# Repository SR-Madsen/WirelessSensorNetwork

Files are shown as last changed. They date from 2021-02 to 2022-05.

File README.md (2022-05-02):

# Wireless Sensor Network
STM32-based project for testing Internet of Things, Ethernet, RFID, and similar technologies.

## Repository Structure
This repository contains a folder for documentation, which includes datasheets and reference manuals used during the design phase as well as other tools and general documents. Additionally, there are folders for the Master board and Slave board. These further includes demo programs used for testing functionality that is possible to test on either the STM32F769-DISCO, STM32L412 Nucleo, or STM32WB55 Nucleo boards. The actual program used for each board is placed in a separate, aptly named, folder. The PCBs themselves are also found as KiCad projects within either the Master or Slave folder.

## Overview
The project will contain one large Master board with many functionalities and several small Slaves only used for measuring sensor values. The slaves are powered by a coin-cell battery, and will thus be in sleep mode most of the time. Occasionally, they will wake and retrieve sensor measurements, which are transmitted over 2.4 GHz ZigBee to the Master. The Master is supplied through USB and will, aside from receiving data from the Slaves, contain an RFID antenna used for detecting valid cards/keys, which allow the user to initiate a data transfer. This data transfer may be through USB or Ethernet, as the Master will host a small webpage containing the data from each Slave.

A full block diagram of the project can be found as draw.io files in the Documentation folder, but is also shown below. In the documentation folder, a LaTeX report can also be found.

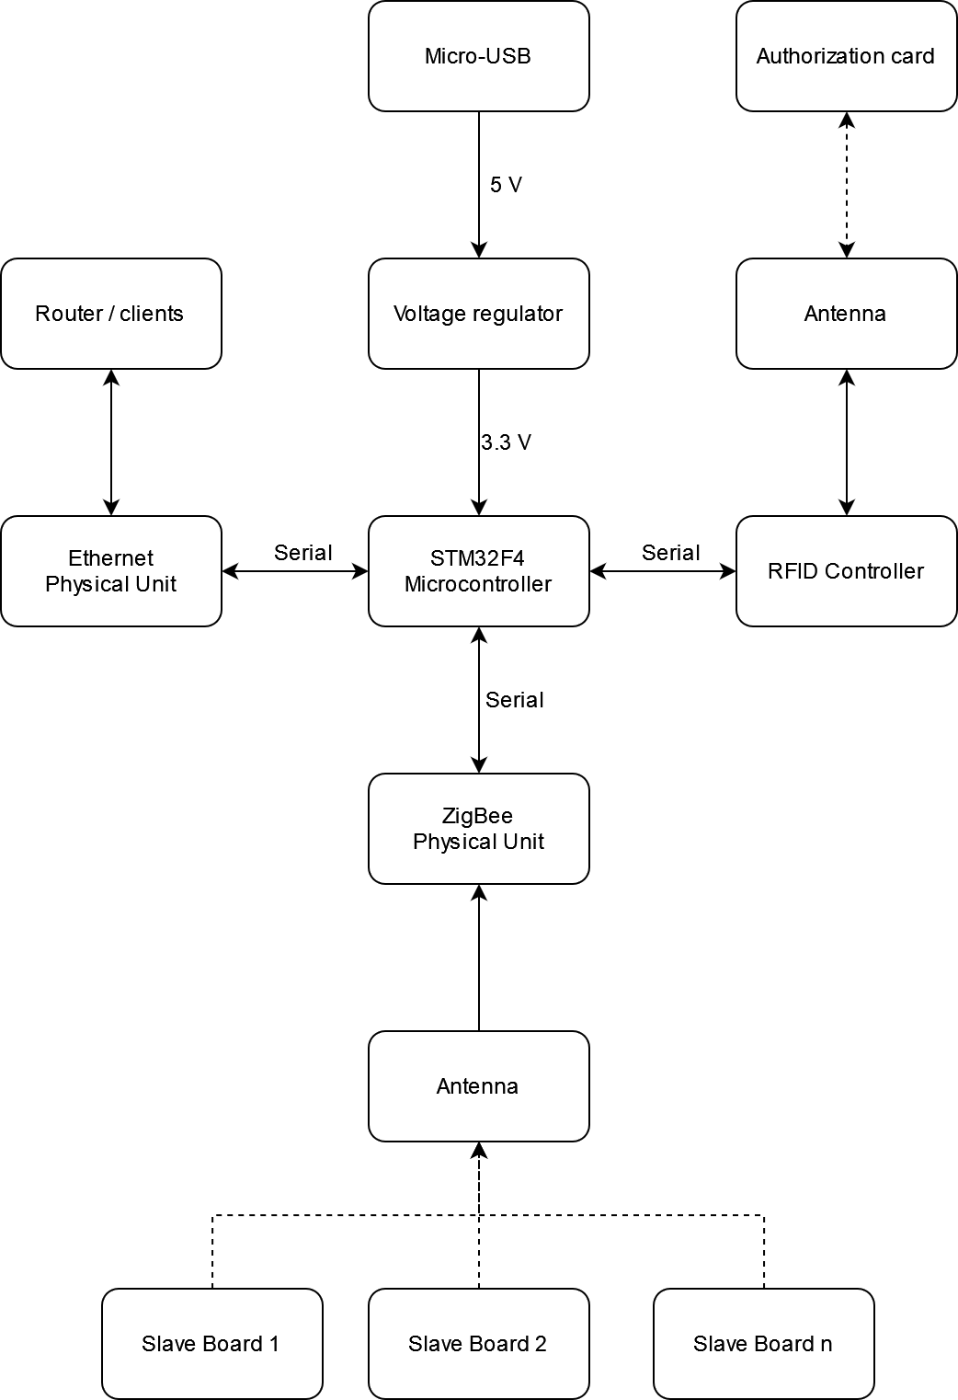
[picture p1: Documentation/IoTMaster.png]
Master board


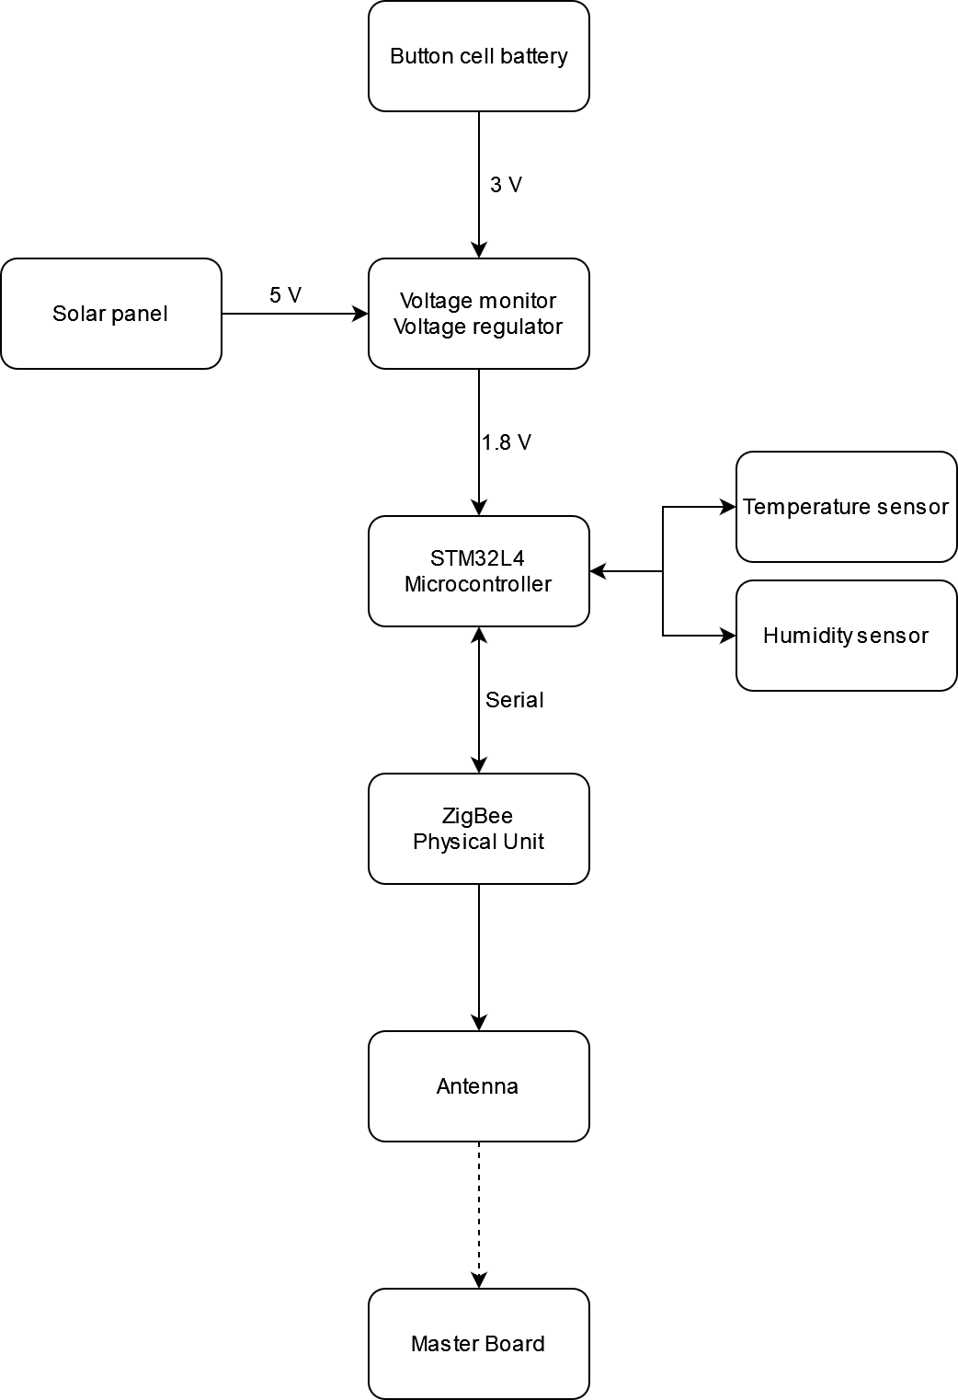
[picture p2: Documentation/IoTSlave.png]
Slave board


## Hardware
The designed PCBs are shown below.

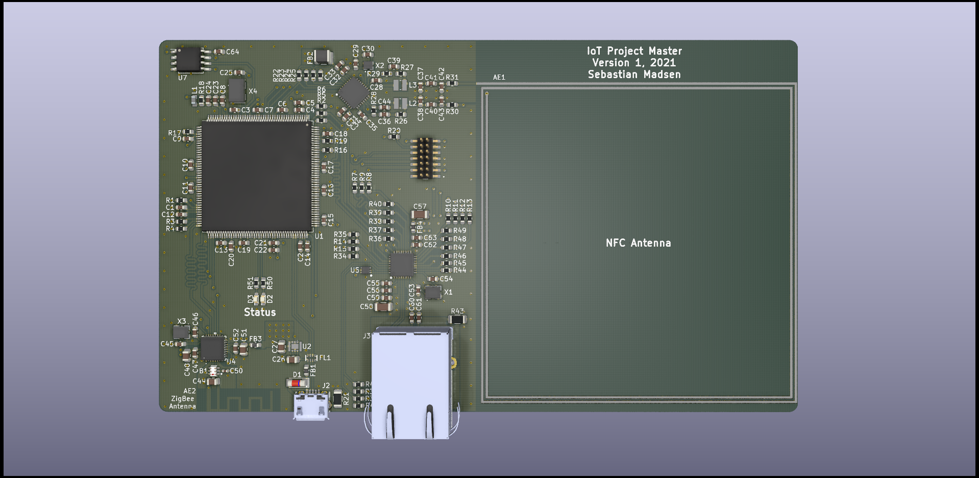
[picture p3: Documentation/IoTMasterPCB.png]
Master PCB


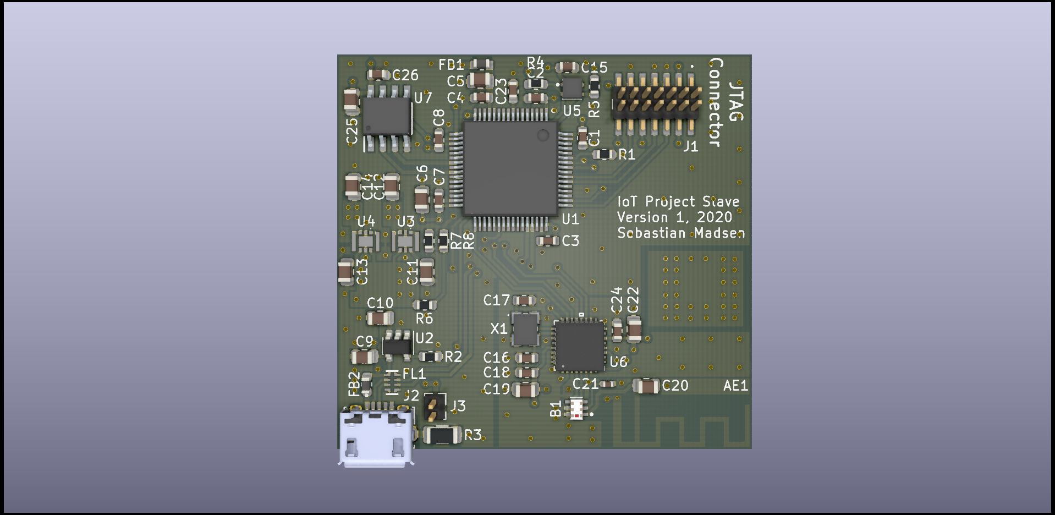
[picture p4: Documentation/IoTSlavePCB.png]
Slave PCB


## Software
By using ST development kits and the STM32Cube ecosystem, preliminary software has been created for both the master and slave.

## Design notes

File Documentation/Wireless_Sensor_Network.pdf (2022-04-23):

# Documentation of

# Wireless Sensor Network

### Sebastian Rud Madsen

### July 2020

1

Sebastian Rud Madsen | Wireless Sensor Network | July 2020

## Contents

1 About | 3
2 Idea | 3
3 Electrical Considerations | 4
4 Mechanical Requirements | 8
5 Hardware Choices | 9
University of Southern Denmark | Page 2 of 13

## 1 About

This documentation is used for thoughts, theory, and calculations in regards to

creating the IoT-like device. The project is to be used as a learning board for low-

power digital uses and IoT technologies, as well as general programming. The design

should mirror realistic engineering principles, with some components being designed

fully, while relevant components are simply bought as integrated circuits.

## 2 Idea

The project will result in slave boards that utilize an STM32L microcontroller in

low-power and shutdown-mode to conserve battery life. The battery should be a

button cell type, like the CR2032 or a rechargeable variant. The microcontroller will

get measurements of temperature and humidity and communicate these through a

wireless IoT communication type to a master controller, which is responsible for

multiple nodes. This will log the data for separate locations and continuously save

these, for example to a web-based solution for graphical output. To incorporate

RFID communication, the master controller could implement one as well, which

would transfer data to USB or similar action when a correct key is detected.

University of Southern Denmark | Page 3 of 13

## 3 Electrical Considerations

This section outlines the considerations and requirements for the electrical parts of

the system.

### 3.1 Analog Circuits

The analog circuits must accommodate the use of a battery. As a small 4-5 V solar

panel is accessible, which can be used to supply current for the circuit. For design

flexibility, both a non-rechargeable and a rechargeable variant of the same battery

will be usable. The rechargeable variant will be powered by the solar panel, which

also supplies the circuits themselves. The battery will supply the current when the

sun is not present. For this reason, a voltage regulator must be used to correct the

voltage for use in the battery. As a common cell battery is 3 V, a similar voltage is

expected for the rechargeable variant. To avoid undervoltage and overvoltage of the

battery, a window comparator or voltage monitor must be used as well as a charging

circuit. To reduce power consumption further, a low-voltage supply should be used.

As a voltage regulator is needed for the solar panel’s voltage output anyways, this

can easily be implemented.

The master controller will not be battery-driven, but instead powered through for

example micro-USB, as it will be placed in a stable environment with easy access to

power sources. It will still need use of a voltage regulator, but is much more flexible.

### 3.2 Digital Circuits

As mentioned, a low-power variant of the STM32 microcontroller will be used to re-

duce strain on the battery. This will be used in shutdown-mode most of the time, and

occasionally in low-power mode for gathering measurements and sending messages.

In shutdown-mode, it is expected to use no more than 250 nA, while it will draw at

most 1 mA when active. Additionally, a transceiver must also be used for the chosen

IoT technology. Once more, this will not use more than 500 nA in shutdown-mode,

but up to 15 mA when transmitting. This will be only for a short amount of time,

with large intervals.

University of Southern Denmark | Page 4 of 13

By estimating use of a 50 mAh battery with a 750 nA stop-mode 99.9% of the

time, only drawing 15 mA 0.1% of the time, the battery will last 132 days without

charging. This means that the microcontroller can transmit for 0.3 seconds every

5 minutes. This seems reasonable for real-life use, as temperatures and humidity

changes very slowly. A more expensive battery will contain a charge of up to 250

mAh, greatly prolonging the lifetime of the slave boards.

The master controller will not be using a battery, and thus its RFID and IoT

transceivers can realistically use any amount of power. The microcontroller used

in the master controller can be any STM-type, so long as it is powerful enough to

collect and distribute data both via antennas and ethernet. Additionally, a flash

storage connected to the microcontroller with QSPI would also be great for storing

the collected data.

### 3.3 RF Technology

As mentioned, RFID will be used for the master controller. This requires an antenna

of a sort, which can simply be routing on the PCB, for example by purchasing an

RFID-RC522 PCB and connecting it to the master controller board. Alternatively,

another option is designing an antenna manually, which requires precision, but is

cheaper and requires less space. As the project should mirror actual in-company

engineering, the latter option is the best.

For communication between master and slave boards, the 2.4 GHz ZigBee protocol

will be used, which is a well-defined IEEE 802.15.4-based specification. The range is

relatively short, but due to the limited distances within the apartment to be used,

this should not matter. There are many alternatives in IoT communication, some of

the biggest being Z-Wave, LoRa, and SigFox. ZigBee has been chosen solely because

it has a cooler logo, as the downsides as opposed to other technologies will not

impact this project.

University of Southern Denmark | Page 5 of 13

### 3.4 Summary

The considerations made through this section is summarized by creating block dia-

grams for both the Master and Slave boards. The Master board block diagram can

be seen in Figure 1, while the Slave block diagram can be seen in Figure 2.

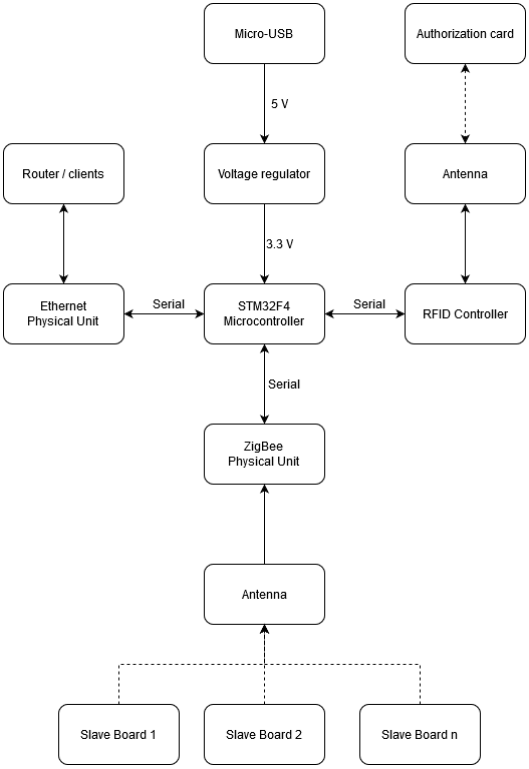
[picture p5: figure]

Figure 1: Block diagram of IoT Project Master Board

University of Southern Denmark | Page 6 of 13

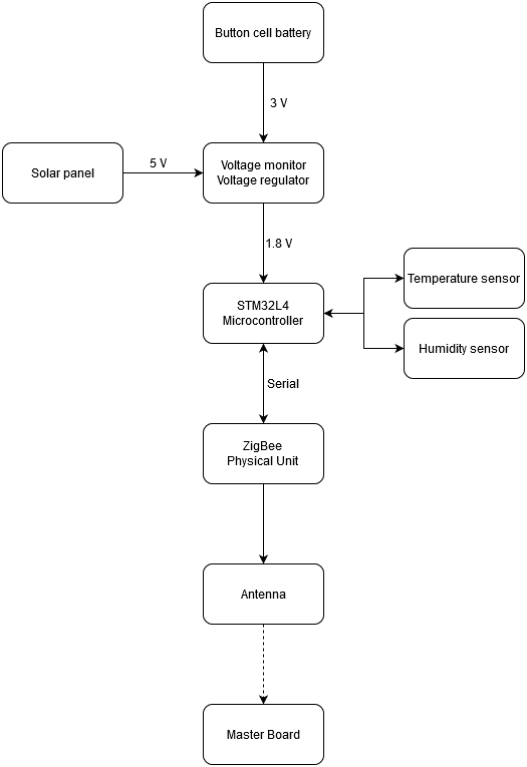
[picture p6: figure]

Figure 2: Block diagram of IoT Project Slave Boards

University of Southern Denmark | Page 7 of 13

## 4 Mechanical Requirements

This section similarly outlines the requirements for the mechanical parts of the

system.

University of Southern Denmark | Page 8 of 13

## 5 Hardware Choices

Using the electrical considerations, hardware can be chosen and electric circuits

designed for both the slaves and master.

### 5.1 Slave Boards

The Slave Boards are designed initially, as they have the most limitations. The

design choices made are clarified in the coming sections.

Microcontroller

A development board with the low-power microcontroller STM32L412RBT6P (https://www.mouser.dk/ProductDetail/STMicroelectronics/STM32L412RBT6P?qs=l7cgNqFNU1hh%252BU1wOZs5Xg%3D%3D) is

available, for which reason the MCU is chosen for the slave board. The additional

benefit of using an L4 microcontroller is the higher performance at lower power,

at a higher cost. The P-suffix indicates that the microcontroller can be used with

an external SMPS, as opposed to internal LDO, for increased power efficiency in

run-mode. This function may be left unused if it is deemed to be too pricey. Flash

memory accessed by QSPI should be placed on the board for future-proofing.

IoT Transceiver

The transceiver chosen for ZigBee is the AT86RF232-ZX from Microchip, (https://www.digikey.com/en/products/detail/microchip-technology/AT86RF232-ZXR/3046266) which is

cheap and allows use of an external antenna, which exists within KiCad. Commu-

nication with the microcontroller is through SPI, and also allows for GPIO pins to

indicate interrupts and reset. The transceiver is clocked by the ECS-160-16-33B-

CKM-TR 16 MHz crystal oscillator. (https://www.mouser.dk/ProductDetail/ECS/ECS-160-16-33B-CKM-TR)

Battery

The battery chosen for the slave board is the LIR2450 with a capacity of 120 mAh

and nominal voltage of 3.6 V. (https://dk.farnell.com/multicomp/lir2450/coin-cell-lithium-120mah-3-6v/dp/2009025) This battery can be recharged with 4.2 V. If the

rechargeable battery is deemed unneeded, a CR2450 can be used instead. This would

have a nominal voltage of 3 V, but a capacity of up to 500 mAh.

University of Southern Denmark | Page 9 of 13

The battery will be placed in the SMTU2450-LF from Renata, (https://www.mouser.dk/ProductDetail/Renata/SMTU2450N-LF-BULK?qs=LsPilcdHE7Gn4SDnejz9jQ%3D%3D) a holder designed for

batteries of size 2450.

The output voltage is regulated to 1.8 V with the MYRGP180100B21RA from Mu-

rata, (https://www.mouser.dk/ProductDetail/Murata-Electronics/MYRGP180100B21RA?qs=xZ%2FP%252Ba9zWqaqKk0PL2xouw%3D%3D) as it has high efficiency and small size. The 1.8 V are supplied instead of battery

voltage as it reduces power consumption of the microcontroller and used ICs. A 1.0

V variant of the MYRGP is used for supplying the core voltage and disabling the

internal LDO of the microcontroller, if found to be efficient.

Due to current consumption, the battery voltage cannot be measured by the mi-

crocontroller. If this is found to be needed, the DC-converter RP605Z183B-E2-F

from Ricoh Electronics (https://www.mouser.dk/ProductDetail/Ricoh-Electronic-Devices-Company/RP605Z183B-E2-F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) has high efficiency for supplying 1.8 V, and also divides the

battery voltage with low current consumption so that it can be measured by the

microcontroller. For the time being, a high-resistance voltage divider is implemented

to measure the voltage. The target current consumption is around 1 µA, which dou-

bles the idle consumption. If this impacts battery life too much, the resistors should

be desoldered.

A connection is made for a solar panel to supply the MCP73831T-2ACI/OT battery

charging IC. (https://www.mouser.dk/ProductDetail/Microchip-Technology/MCP73831T-2ACI-OT) This IC automatically regulates the voltage to supply a Lithium-Ion

battery with 4.2 V, and is designed to automatically end the charging when the

current falls below a threshold, as determined by the battery datasheet. Aside from

the solar panel, a USB connector is also connected to the IC, allowing a USB cable

to charge the battery as well. The USB data is connected to the microcontroller for

future-proofing.

Sensors

Both a temperature and humidity sensor is needed for the slave board. While tem-

perature sensors exist in many varieties, humidity sensors generally only exist as ICs

that must be communicated with to retrieve data. The two-in-one solution SHTC3

from Sensirion (https://www.mouser.dk/ProductDetail/Sensirion/SHTC3?qs=y6ZabgHbY%252Bx3LlA87fqBwg%3D%3D) contains both a temperature and humidity sensor with accuracies

of ±0.2◦ C and ±2% respectively. The IC can be supplied by as little as 1.62 V,

communicates with I2C, and has an accuracy up to 16 bits. All this in a DFN-4

SMD package. The IC is low-power and has sleep-mode capabilities.

University of Southern Denmark | Page 10 of 13

The battery voltage may also need to be measured. This is easily implemented by a

resistor divider and measuring with the microcontroller ADC, however this increases

power consumption.

University of Southern Denmark | Page 11 of 13

### 5.2 Master Board

With the Slave Board design in place, the Master Board can now be designed to

interface with these. There are fewer limitations, as size and power consumption is

not crucial.

Microcontroller

An earlier project used the STM32F469II (https://www.mouser.dk/ProductDetail/STMicroelectronics/STM32F469IIT6?qs=54zSKtPzVEduBefFFfD6yA%3D%3D) high-performance microcontroller, which

has the connections needed for ethernet, QSPI, and multiple RF PHYs. For this

reason, it will be used on the master board. In the event that the microcontroller is

not available, the STM32MP151 (https://www.mouser.dk/ProductDetail/STMicroelectronics/STM32MP151AAD3?qs=9r4v7xj2LnmwSDkvuTLGSw%3D%3D) microprocessor series is cheaper and faster, while

still allowing all the needed connections. This would allow it run Embedded Linux

for webpage hosting, although it would make the PCB much more complex due to

the large amount of RAM needed for this. Another drawback is the BGA package,

which is more difficult to use for designs and to place for soldering.

The 32 Mbit QSPI NOR flash memory W25Q32JVSS (https://www.mouser.dk/ProductDetail/Winbond/W25Q32JVSSIQS?qs=wnTfsH77Xs7rrxn05H%252BMrQ%3D%3D) is chosen for storing data.

IoT Transceivers

The Master Controller will use the same Zigbee transceiver.

For NFC communication, the CLRC66303HNY from NXP Semiconductor (https://www.mouser.dk/ProductDetail/NXP-Semiconductors/CLRC66303HNY?qs=gH1BdSMZm8V9YDgcadCntw%3D%3D) will be

used as front-end for transceiving. It will be clocked by an ECS 27.12 MHz Crystal

Oscillator chosen according to datasheet specifications. (https://www.mouser.dk/ProductDetail/ECS/ECS-2712-10-37-AGN-TR?qs=wd5RIQLrsJh5Ncp2%2FUtxhw%3D%3D)

The RFID/NFC antenna can be designed with the NXP NFC Antenna Design Tool. (https://www.nxp.com/products/rfid-nfc/nfc-hf/nfc-readers/nfc-antenna-design-hub:NFC-ANTENNA-DESIGN-TOOL)

Ethernet

The Ethernet on the Master Board will be using the MII protocol between the

microcontroller and Ethernet PHY. The PHY chosen is the KSZ8081MNX. (https://www.mouser.dk/ProductDetail/Microchip-Technology-Micrel/KSZ8081MNXIA-TR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) This

allows transfer rates up to 100 Mbit/s. The IC’s supply is well-filtered, and pull-up

and pull-down resistors are added for correct configuration.

The differential output signals for Tx and Rx are routed to an RJ45 with integrated

magnetics and LEDs. (https://www.mouser.dk/ProductDetail/Wurth-Elektronik/74980104400?qs=T3oQrply3y8TiWjfK%2F4AEQ%3D%3D)

University of Southern Denmark | Page 12 of 13

Power Supply

The Master Board will be supplied through a micro-USB connection to a charger,

PC, or other module. This 5 V supply must be filtered. As none of the modules can

use the 5 V supply directly, it must be converted. It is estimated that no more than

500 mA at 3.3 V will be used under any circumstances. For converting from 5 V to

3.3 V, the Murata MYRGP330100B21RA high-efficiency converter, (https://www.mouser.dk/ProductDetail/Murata-Electronics/MYRGP330100B21RA?qs=xZ%2FP%252Ba9zWqZm9TTCiIsITQ%3D%3D) with an output

current up to 1 A, is chosen.

University of Southern Denmark | Page 13 of 13

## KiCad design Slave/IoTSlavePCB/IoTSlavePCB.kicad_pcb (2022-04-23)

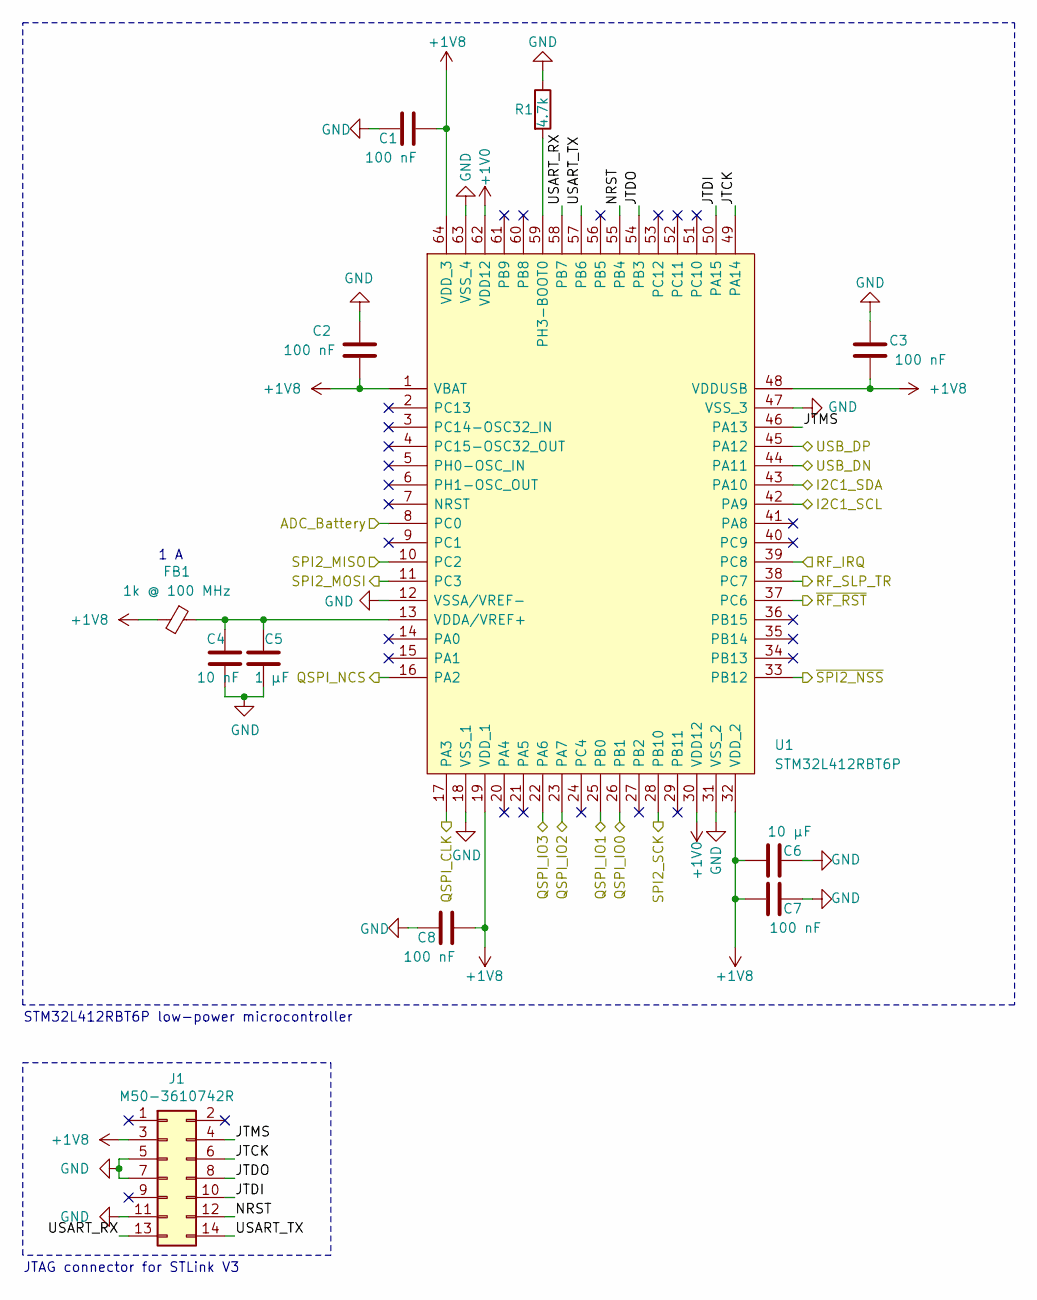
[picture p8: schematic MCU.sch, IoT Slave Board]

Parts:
C1, C2, C3, C7, C8: 100 nF; C_0603_1608Metric
C4: 10 nF; C_0603_1608Metric
C5: 1 µF; C_0805_2012Metric
C6: 10 µF; C_0805_2012Metric
FB1: 1k @ 100 MHz; L_0603_1608Metric
J1: M50-3610742R
R1: 4.7k; R_0603_1608Metric
U1: STM32L412RBT6P; Manufacturer_Part_Number STM32L412RBT6P; Mouser Part Number 511-STM32L412RBT6P

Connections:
+1V0: U1.30 (VDD12), U1.62 (VDD12); also elsewhere on the board
+1V8: C1.2, C2.2, C3.1, C6.1, C7.1, C8.2, FB1.2, J1.3, U1.1 (VBAT), U1.19 (VDD_1), U1.32 (VDD_2), U1.48 (VDDUSB), U1.64 (VDD_3); also elsewhere on the board
/MCU/ADC_Battery: U1.8 (PC0); also elsewhere on the board
/MCU/I2C1_SCL: U1.42 (PA9); also elsewhere on the board
/MCU/I2C1_SDA: U1.43 (PA10); also elsewhere on the board
/MCU/JTCK: J1.6, U1.49 (PA14)
/MCU/JTDI: J1.10, U1.50 (PA15)
/MCU/JTDO: J1.8, U1.54 (PB3)
/MCU/JTMS: J1.4, U1.46 (PA13)
/MCU/NRST: J1.12, U1.55 (PB4)
/MCU/QSPI_CLK: U1.17 (PA3); also elsewhere on the board
/MCU/QSPI_NCS: U1.16 (PA2); also elsewhere on the board
/MCU/RF_SLP_TR: U1.38 (PC7); also elsewhere on the board
/MCU/SPI2_MISO: U1.10 (PC2); also elsewhere on the board
/MCU/SPI2_MOSI: U1.11 (PC3); also elsewhere on the board
/MCU/SPI2_SCK: U1.28 (PB10); also elsewhere on the board
/MCU/USART_RX: J1.13, U1.58 (PB7)
/MCU/USART_TX: J1.14, U1.57 (PB6)
/MCU/USB_DN: U1.44 (PA11); also elsewhere on the board
/MCU/USB_DP: U1.45 (PA12); also elsewhere on the board
/MCU/~RF_RST: U1.37 (PC6); also elsewhere on the board
/MCU/~SPI2_NSS: U1.33 (PB12); also elsewhere on the board
/Memory/QSPI_DATA0: U1.26 (PB1); also elsewhere on the board
/Memory/QSPI_DATA1: U1.25 (PB0); also elsewhere on the board
/Memory/QSPI_DATA2: U1.23 (PA7); also elsewhere on the board
/Memory/QSPI_DATA3: U1.22 (PA6); also elsewhere on the board
/ZigBee/IRQ: U1.39 (PC8); also elsewhere on the board
GND: C1.1, C2.1, C3.2, C4.2, C5.2, C6.2, C7.2, C8.1, J1.5, J1.7, J1.11, R1.1, U1.12 (VSSA/VREF-), U1.18 (VSS_1), U1.31 (VSS_2), U1.47 (VSS_3), U1.63 (VSS_4); also elsewhere on the board
unnamed: C4.1, C5.1, FB1.1, U1.13 (VDDA/VREF+)
unnamed: R1.2, U1.59 (PH3-BOOT0)

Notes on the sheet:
JTAG connector for STLink V3
STM32L412RBT6P low-power microcontroller
1 A

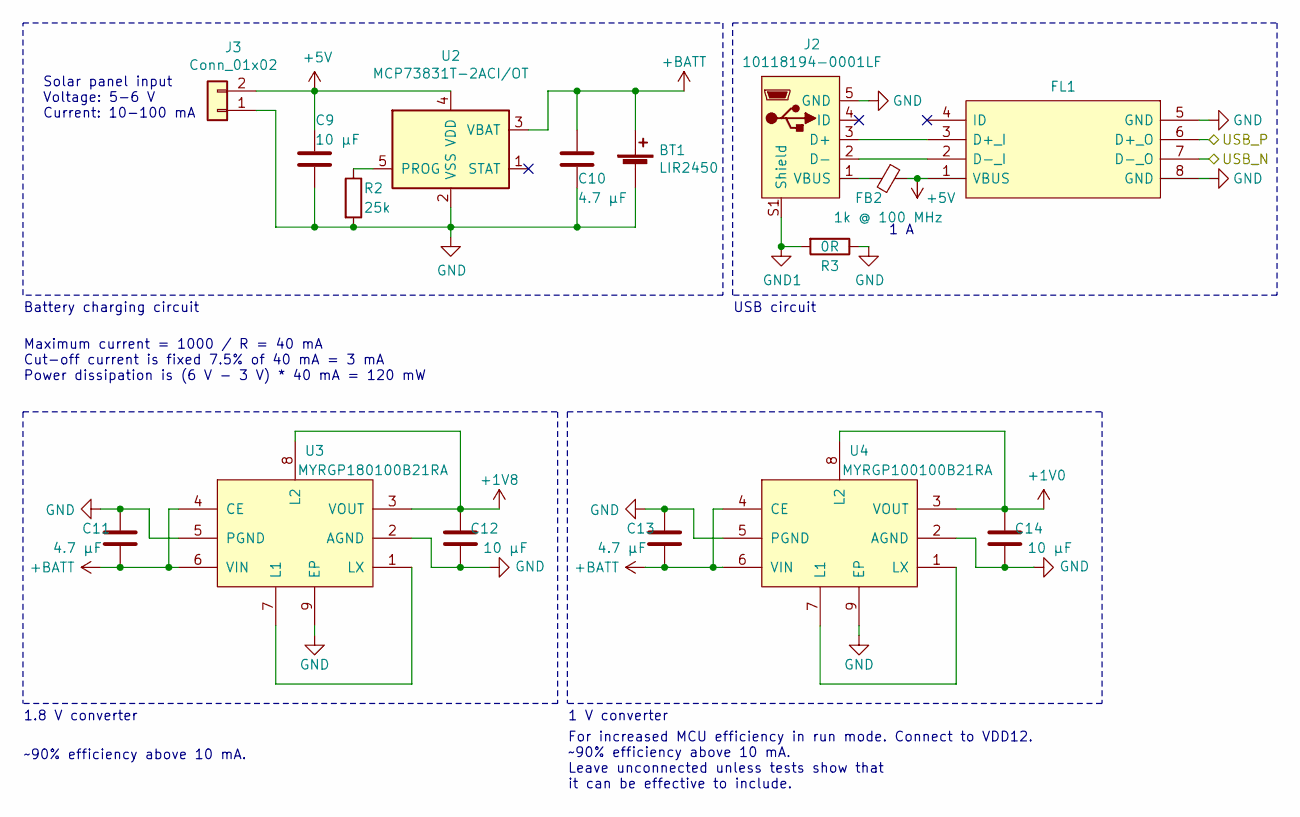
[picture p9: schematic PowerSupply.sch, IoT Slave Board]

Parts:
BT1: LIR2450; SMTU2450-LF
C9, C12, C14: 10 µF; C_0805_2012Metric
C10, C11, C13: 4.7 µF; C_0805_2012Metric
FB2: 1k @ 100 MHz; L_0603_1608Metric
FL1: ECMF02-4CMX8; ECMF024CMX8; Manufacturer_Part_Number ECMF02-4CMX8; Mouser Part Number 511-ECMF02-4CMX8
J2: 10118194-0001LF
J3: Conn_01x02; PinHeader_1x02_P1.27mm_Vertical
R2: 25k; R_0603_1608Metric
R3: 0R; R_1206_3216Metric
U2: MCP73831T-2ACI/OT; SOT-23-5
U3: MYRGP180100B21RA
U4: MYRGP100100B21RA; MYRGP180100B21RA

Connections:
+1V0: C14.2, U4.3 (VOUT), U4.8 (L2); also elsewhere on the board
+1V8: C12.2, U3.3 (VOUT), U3.8 (L2); also elsewhere on the board
+5V: C9.1, FB2.1, FL1.1 (VBUS), J3.2, U2.4 (VDD)
+BATT: BT1.1 (+), C10.1, C11.2, C13.2, U2.3 (VBAT), U3.4 (CE), U3.6 (VIN), U4.4 (CE), U4.6 (VIN); also elsewhere on the board
/MCU/USB_DN: FL1.7 (D-_O); also elsewhere on the board
/MCU/USB_DP: FL1.6 (D+_O); also elsewhere on the board
GND: BT1.2 (-), C9.2, C10.2, C11.1, C12.1, C13.1, C14.1, FL1.5 (GND), FL1.8 (GND), J2.5 (GND), J3.1, R2.2, R3.1, U2.2 (VSS), U3.2 (AGND), U3.5 (PGND), U3.9 (EP), U4.2 (AGND), U4.5 (PGND), U4.9 (EP); also elsewhere on the board
GND1: J2.S1 (Shield), R3.2
unnamed: FB2.2, J2.1 (VBUS)
unnamed: FL1.2 (D-_I), J2.2 (D-)
unnamed: FL1.3 (D+_I), J2.3 (D+)
unnamed: R2.1, U2.5 (PROG)
unnamed: U3.1 (LX), U3.7 (L1)
unnamed: U4.1 (LX), U4.7 (L1)

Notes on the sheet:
Solar panel input Voltage: 5-6 V Current: 10-100 mA
Maximum current = 1000 / R = 40 mA Cut-off current is fixed 7.5% of 40 mA = 3 mA Power dissipation is (6 V - 3 V) * 40 mA = 120 mW
Battery charging circuit
1.8 V converter
~~90% efficiency above 10 mA.
1 V converter
For increased MCU efficiency in run mode. Connect to VDD12. ~~90% efficiency above 10 mA. Leave unconnected unless tests show that it can be effective to include.
1 A
USB circuit

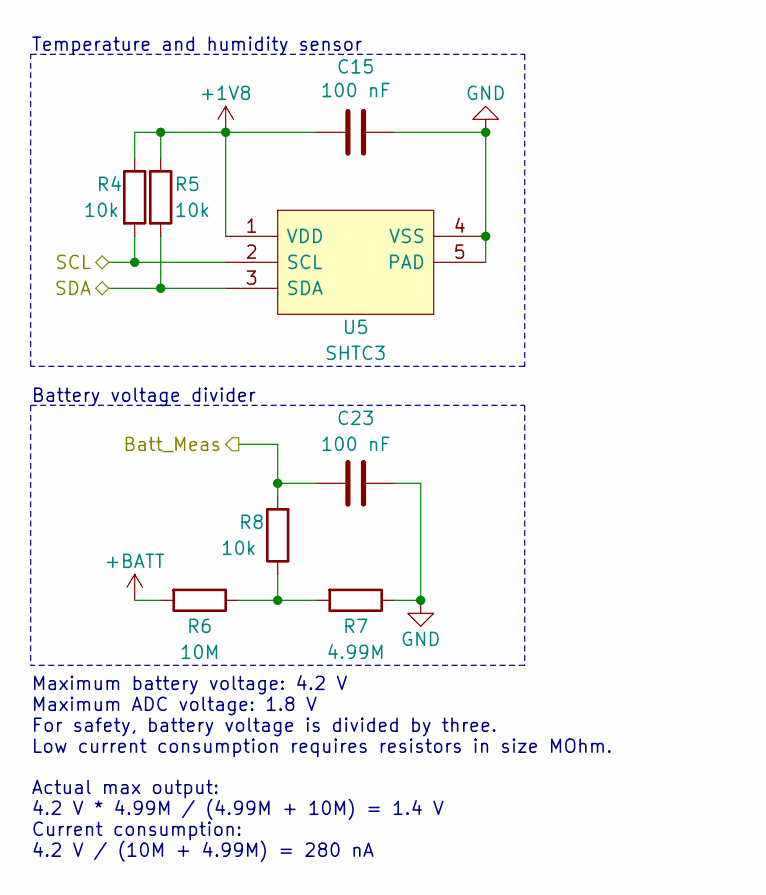
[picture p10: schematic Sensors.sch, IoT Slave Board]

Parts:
C15, C23: 100 nF; C_0603_1608Metric
R4, R5, R8: 10k; R_0603_1608Metric
R6: 10M; R_0603_1608Metric
R7: 4.99M; R_0603_1608Metric
U5: SHTC3; Manufacturer_Part_Number SHTC3; Mouser Part Number 403-SHTC3

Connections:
+1V8: C15.2, R4.1, R5.1, U5.1 (VDD); also elsewhere on the board
+BATT: R6.2; also elsewhere on the board
/MCU/ADC_Battery: C23.2, R8.2; also elsewhere on the board
/MCU/I2C1_SCL: R4.2, U5.2 (SCL); also elsewhere on the board
/MCU/I2C1_SDA: R5.2, U5.3 (SDA); also elsewhere on the board
GND: C15.1, C23.1, R7.1, U5.4 (VSS), U5.5 (PAD); also elsewhere on the board
unnamed: R6.1, R7.2, R8.1

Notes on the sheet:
Temperature and humidity sensor
Battery voltage divider
Maximum battery voltage: 4.2 V Maximum ADC voltage: 1.8 V For safety, battery voltage is divided by three. Low current consumption requires resistors in size MOhm.
Actual max output: 4.2 V * 4.99M / (4.99M + 10M) = 1.4 V Current consumption: 4.2 V / (10M + 4.99M) = 280 nA

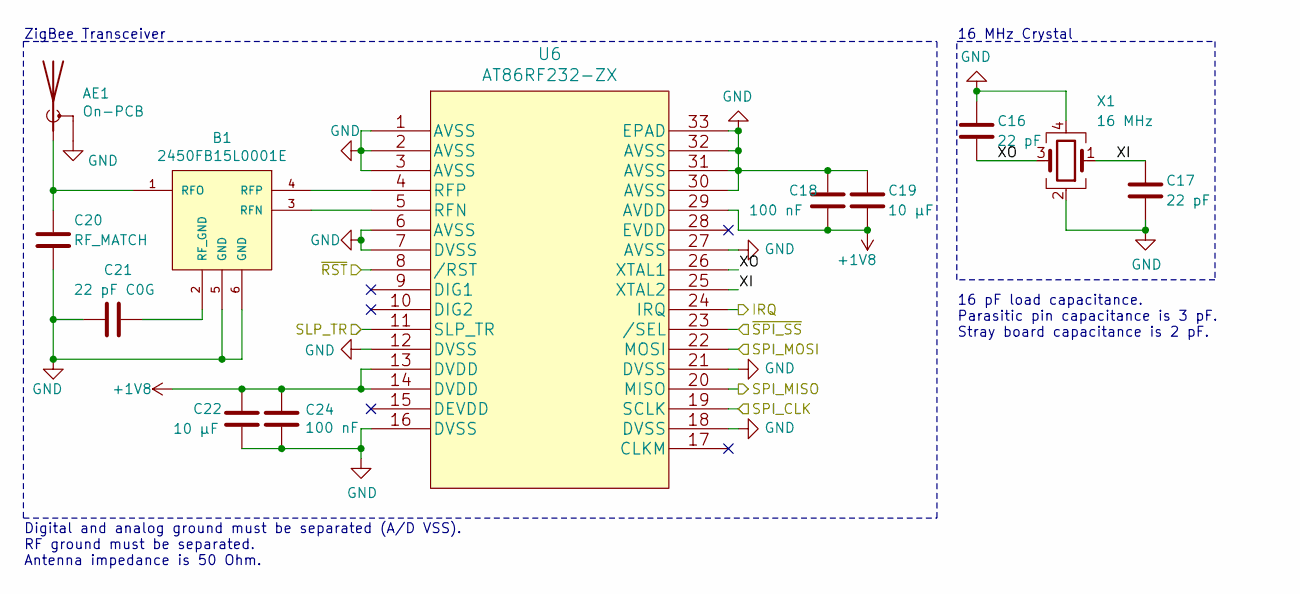
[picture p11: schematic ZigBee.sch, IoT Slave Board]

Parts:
AE1: On-PCB; Texas_SWRA117D_2.4GHz_Left
B1: 2450FB15L0001E
C16, C17: 22 pF; C_0603_1608Metric
C18, C24: 100 nF; C_0603_1608Metric
C19, C22: 10 µF; C_0805_2012Metric
C20: RF_MATCH; C_0805_2012Metric
C21: 22 pF C0G; C_0402_1005Metric; Part 500R07S220JV4 recommended
U6: AT86RF232-ZX
X1: 16 MHz; ECS1601633BCKMTR

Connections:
+1V8: C18.2, C19.2, C22.1, C24.1, U6.13 (DVDD), U6.14 (DVDD), U6.29 (AVDD); also elsewhere on the board
/MCU/RF_SLP_TR: U6.11 (SLP_TR); also elsewhere on the board
/MCU/SPI2_MISO: U6.20 (MISO); also elsewhere on the board
/MCU/SPI2_MOSI: U6.22 (MOSI); also elsewhere on the board
/MCU/SPI2_SCK: U6.19 (SCLK); also elsewhere on the board
/MCU/~RF_RST: U6.8 (/RST); also elsewhere on the board
/MCU/~SPI2_NSS: U6.23 (/SEL); also elsewhere on the board
/ZigBee/IRQ: U6.24 (IRQ); also elsewhere on the board
/ZigBee/XI: C17.1, U6.25 (XTAL2), X1.1
/ZigBee/XO: C16.2, U6.26 (XTAL1), X1.3
GND: AE1.2 (Shield), B1.5 (GND), B1.6 (GND), C16.1, C17.2, C18.1, C19.1, C20.2, C21.2, C22.2, C24.2, U6.1 (AVSS), U6.2 (AVSS), U6.3 (AVSS), U6.6 (AVSS), U6.7 (DVSS), U6.12 (DVSS), U6.16 (DVSS), U6.18 (DVSS), U6.21 (DVSS), U6.27 (AVSS), U6.30 (AVSS), U6.31 (AVSS), U6.32 (AVSS), U6.33 (EPAD), X1.2, X1.4; also elsewhere on the board
unnamed: AE1.1 (A), B1.1 (RFO), C20.1
unnamed: B1.2 (RF_GND), C21.1
unnamed: B1.3 (RFN), U6.5 (RFN)
unnamed: B1.4 (RFP), U6.4 (RFP)

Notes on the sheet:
16 pF load capacitance. Parasitic pin capacitance is 3 pF. Stray board capacitance is 2 pF.
16 MHz Crystal
Digital and analog ground must be separated (A/D VSS). RF ground must be separated. Antenna impedance is 50 Ohm.
ZigBee Transceiver

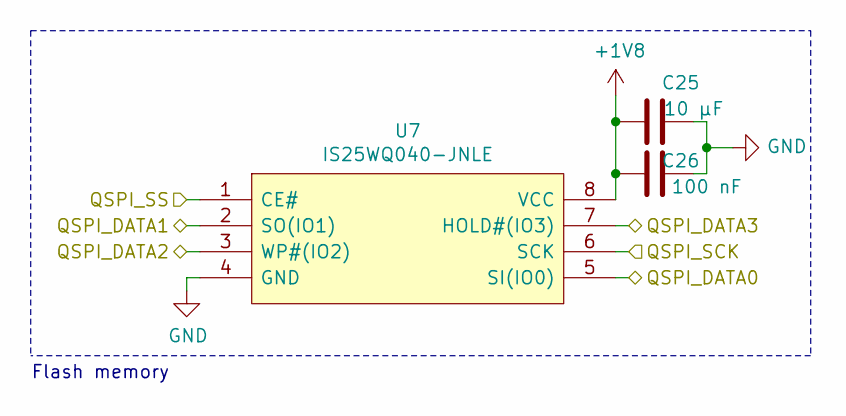
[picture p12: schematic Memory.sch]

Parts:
C25: 10 µF; C_0805_2012Metric
C26: 100 nF; C_0603_1608Metric
U7: IS25WQ040-JNLE; Manufacturer_Part_Number IS25WQ040-JNLE; Mouser Part Number 870-IS25WQ040-JNLE

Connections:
+1V8: C25.2, C26.2, U7.8 (VCC); also elsewhere on the board
/MCU/QSPI_CLK: U7.6 (SCK); also elsewhere on the board
/MCU/QSPI_NCS: U7.1 (CE#); also elsewhere on the board
/Memory/QSPI_DATA0: U7.5 (SI(IO0)); also elsewhere on the board
/Memory/QSPI_DATA1: U7.2 (SO(IO1)); also elsewhere on the board
/Memory/QSPI_DATA2: U7.3 (WP#(IO2)); also elsewhere on the board
/Memory/QSPI_DATA3: U7.7 (HOLD#(IO3)); also elsewhere on the board
GND: C25.1, C26.1, U7.4 (GND); also elsewhere on the board

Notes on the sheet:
Flash memory

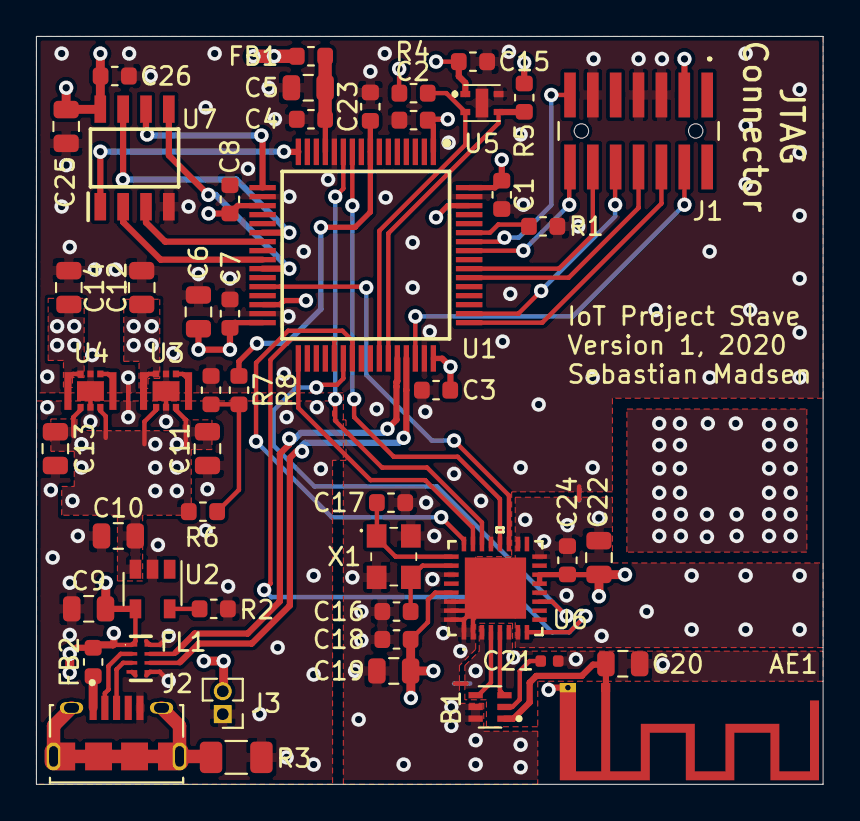
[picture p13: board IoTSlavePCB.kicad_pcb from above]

Board: 4 copper layers, 43.7 x 41.5 mm, 51 parts (1 on the bottom side), 46 nets.

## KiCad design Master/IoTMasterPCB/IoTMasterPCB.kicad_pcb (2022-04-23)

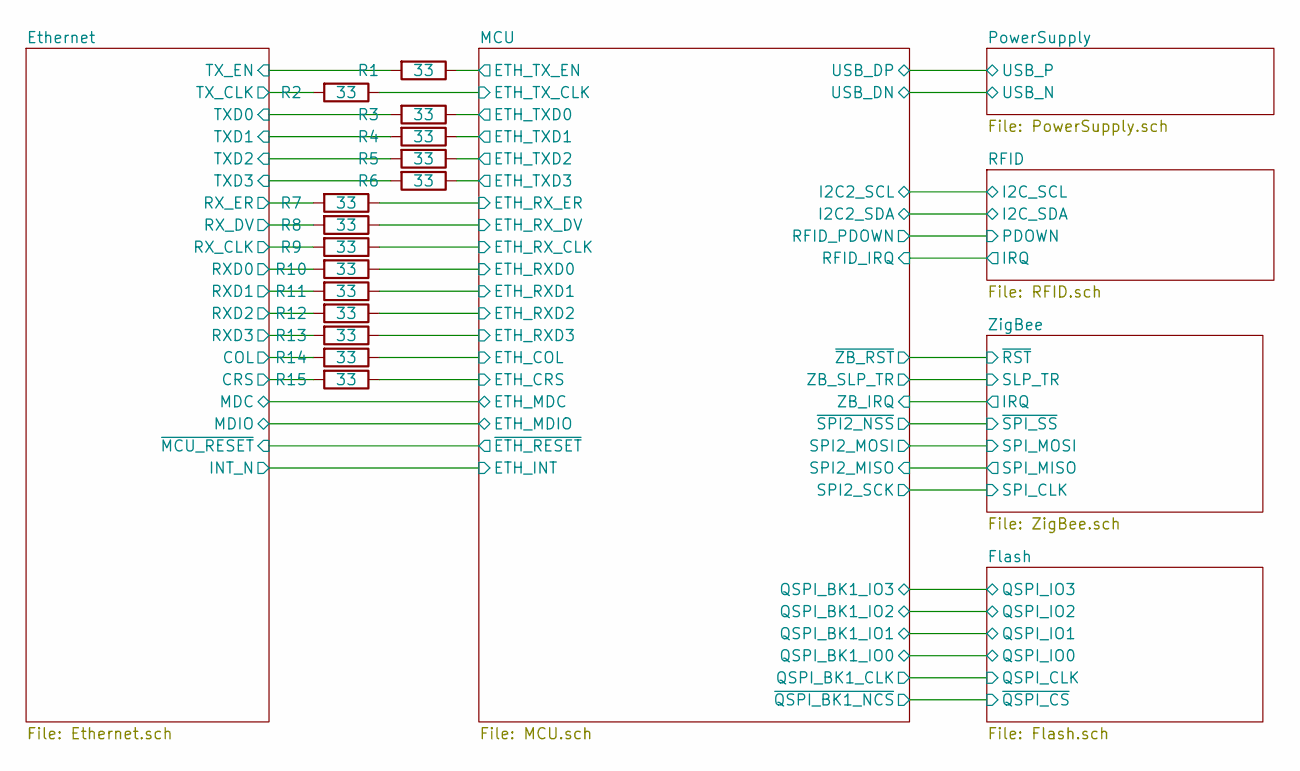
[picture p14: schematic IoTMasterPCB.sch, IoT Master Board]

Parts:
R1, R2, R3, R4, R5, R6, R7, R8, R9, R10, R11, R12, R13, R14, R15: 33; R_0603_1608Metric

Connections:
/Ethernet/COL: R14.2; also elsewhere on the board
/Ethernet/CRS: R15.2; also elsewhere on the board
/Ethernet/RXD0: R10.2; also elsewhere on the board
/Ethernet/RXD1: R11.2; also elsewhere on the board
/Ethernet/RXD2: R12.2; also elsewhere on the board
/Ethernet/RXD3: R13.2; also elsewhere on the board
/Ethernet/RX_CLK: R9.2; also elsewhere on the board
/Ethernet/RX_DV: R8.2; also elsewhere on the board
/Ethernet/RX_ER: R7.2; also elsewhere on the board
/Ethernet/TXD0: R3.2; also elsewhere on the board
/Ethernet/TXD1: R4.2; also elsewhere on the board
/Ethernet/TXD2: R5.2; also elsewhere on the board
/Ethernet/TXD3: R6.2; also elsewhere on the board
/Ethernet/TX_CLK: R2.2; also elsewhere on the board
/Ethernet/TX_EN: R1.2; also elsewhere on the board
/MCU/ETH_COL: R14.1; also elsewhere on the board
/MCU/ETH_CRS: R15.1; also elsewhere on the board
/MCU/ETH_RXD0: R10.1; also elsewhere on the board
/MCU/ETH_RXD1: R11.1; also elsewhere on the board
/MCU/ETH_RXD2: R12.1; also elsewhere on the board
/MCU/ETH_RXD3: R13.1; also elsewhere on the board
/MCU/ETH_RX_CLK: R9.1; also elsewhere on the board
/MCU/ETH_RX_DV: R8.1; also elsewhere on the board
/MCU/ETH_RX_ER: R7.1; also elsewhere on the board
/MCU/ETH_TXD0: R3.1; also elsewhere on the board
/MCU/ETH_TXD1: R4.1; also elsewhere on the board
/MCU/ETH_TXD2: R5.1; also elsewhere on the board
/MCU/ETH_TXD3: R6.1; also elsewhere on the board
/MCU/ETH_TX_CLK: R2.1; also elsewhere on the board
/MCU/ETH_TX_EN: R1.1; also elsewhere on the board

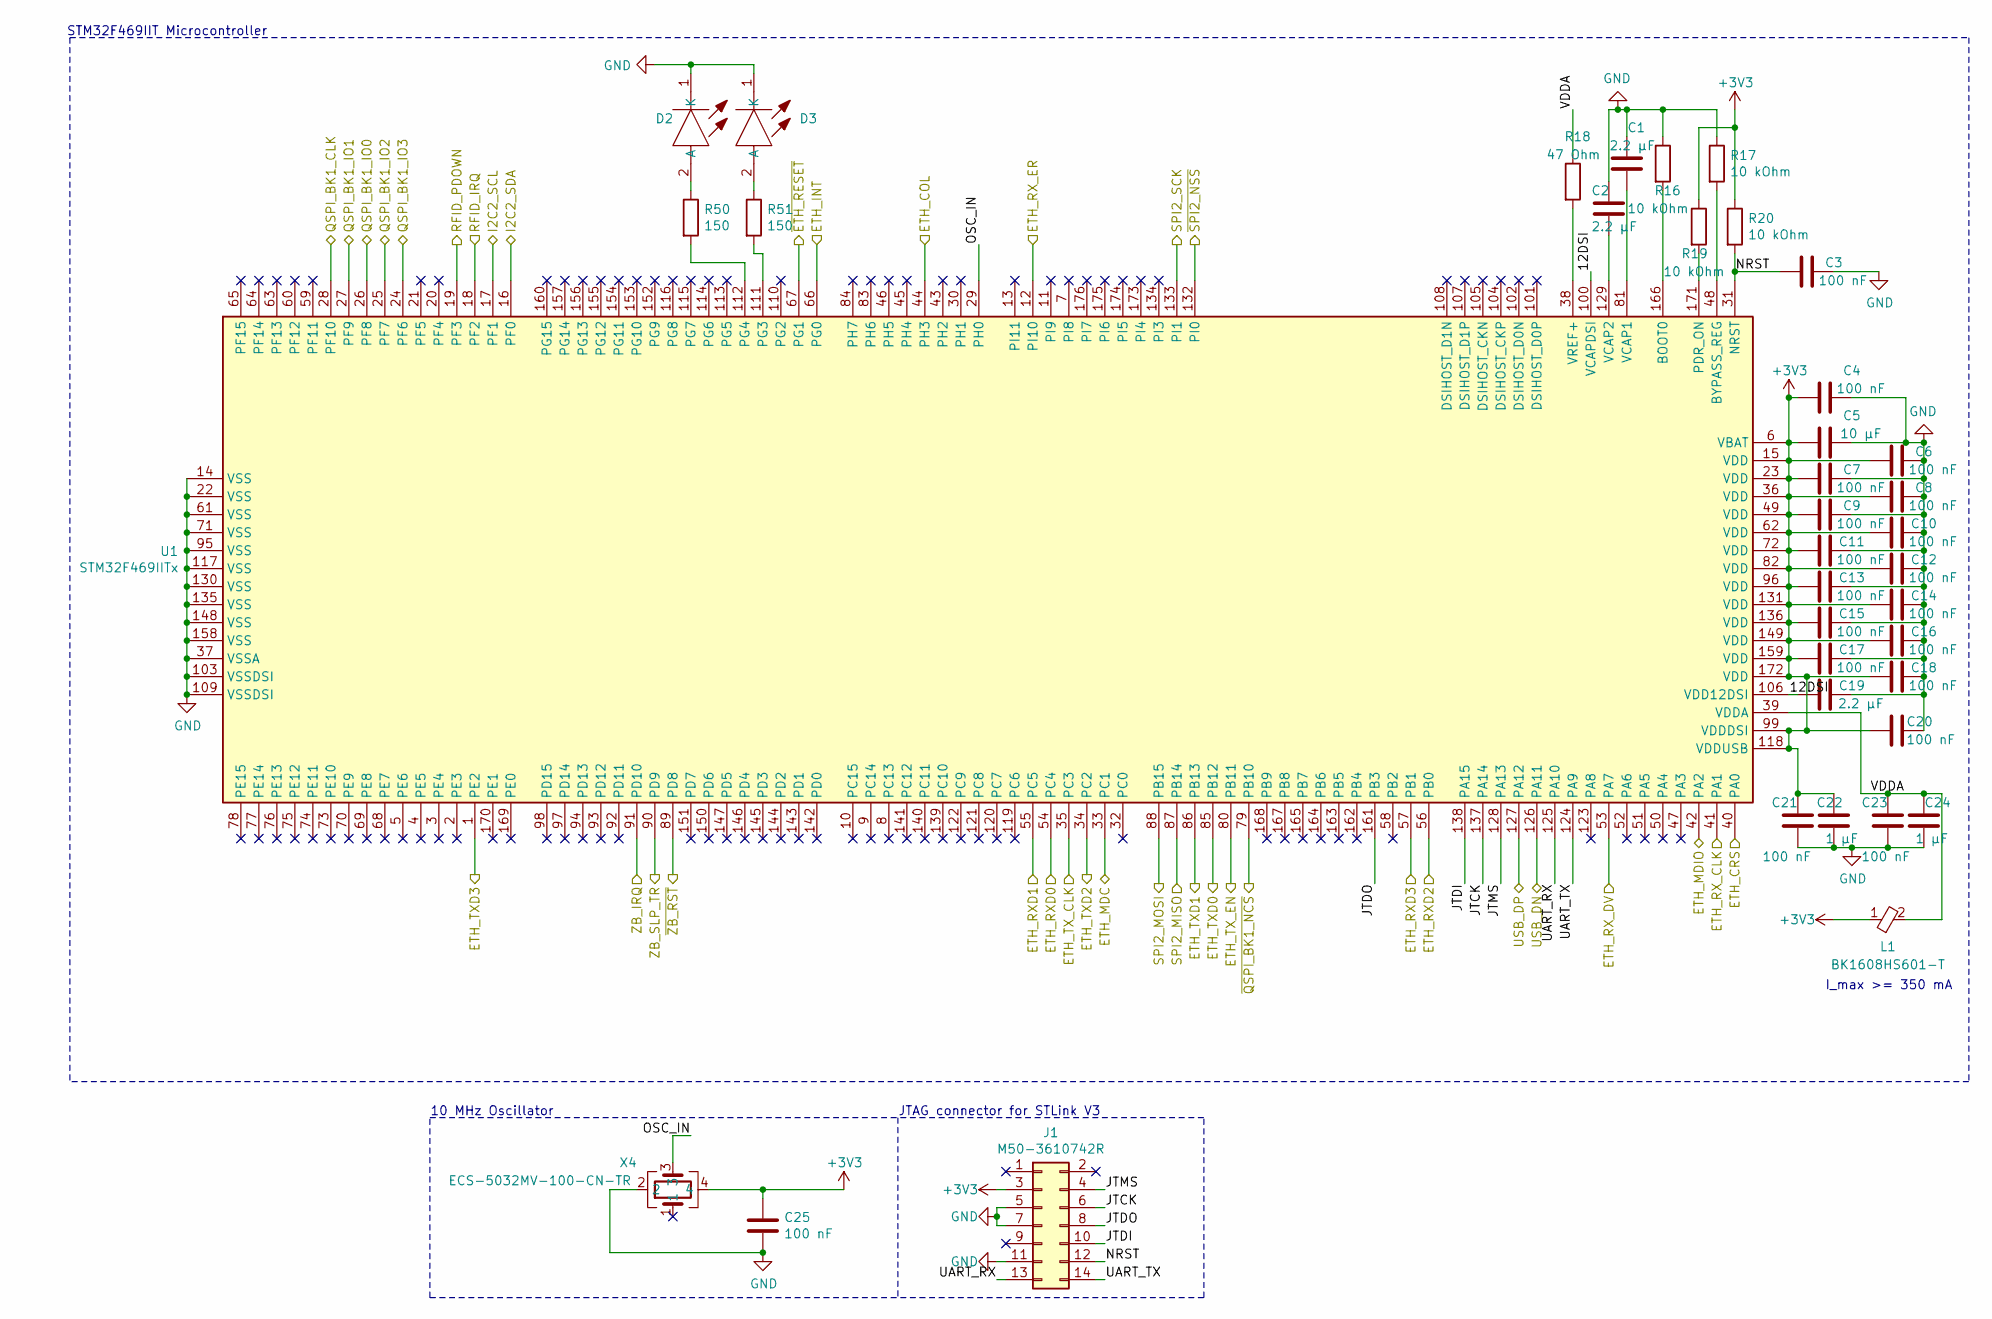
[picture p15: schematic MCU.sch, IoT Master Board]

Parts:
C1, C2, C19: 2.2 µF; C_0603_1608Metric
C3, C4, C6, C7, C8, C9, C10, C11, C12, C13, C14, C15, C16, C17, C18, C20, C21, C23, C25: 100 nF; C_0603_1608Metric
C5: 10 µF; C_0603_1608Metric
C22, C24: 1 µF; C_0603_1608Metric
D2: 150060SS55040; 150060VS55040; Mouser Part Number 710-150060SS55040
D3: 150060VS55040; Mouser Part Number 710-150060VS55040
J1: M50-3610742R
L1: BK1608HS601-T
R16, R17, R19, R20: 10 kOhm; R_0603_1608Metric
R18: 47 Ohm; R_0603_1608Metric
R50, R51: 150; R_0603_1608Metric
U1: STM32F469IITx; LQFP-176_24x24mm_P0.5mm
X4: ECS-5032MV-100-CN-TR; ECS5032MV250CNTR; Mouser Part Number 520-5032MV-250-CNT

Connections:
/MCU/12DSI: C19.2, U1.100 (VCAPDSI), U1.106 (VDD12DSI)
/MCU/ETH_COL: U1.44 (PH3); also elsewhere on the board
/MCU/ETH_CRS: U1.40 (PA0); also elsewhere on the board
/MCU/ETH_INT: U1.66 (PG0); also elsewhere on the board
/MCU/ETH_MDC: U1.33 (PC1); also elsewhere on the board
/MCU/ETH_MDIO: U1.42 (PA2); also elsewhere on the board
/MCU/ETH_RXD0: U1.54 (PC4); also elsewhere on the board
/MCU/ETH_RXD1: U1.55 (PC5); also elsewhere on the board
/MCU/ETH_RXD2: U1.56 (PB0); also elsewhere on the board
/MCU/ETH_RXD3: U1.57 (PB1); also elsewhere on the board
/MCU/ETH_RX_CLK: U1.41 (PA1); also elsewhere on the board
/MCU/ETH_RX_DV: U1.53 (PA7); also elsewhere on the board
/MCU/ETH_RX_ER: U1.12 (PI10); also elsewhere on the board
/MCU/ETH_TXD0: U1.85 (PB12); also elsewhere on the board
/MCU/ETH_TXD1: U1.86 (PB13); also elsewhere on the board
/MCU/ETH_TXD2: U1.34 (PC2); also elsewhere on the board
/MCU/ETH_TXD3: U1.1 (PE2); also elsewhere on the board
/MCU/ETH_TX_CLK: U1.35 (PC3); also elsewhere on the board
/MCU/ETH_TX_EN: U1.80 (PB11); also elsewhere on the board
/MCU/I2C2_SCL: U1.17 (PF1); also elsewhere on the board
/MCU/I2C2_SDA: U1.16 (PF0); also elsewhere on the board
/MCU/JTCK: J1.6, U1.137 (PA14)
/MCU/JTDI: J1.10, U1.138 (PA15)
/MCU/JTDO: J1.8, U1.161 (PB3)
/MCU/JTMS: J1.4, U1.128 (PA13)
/MCU/NRST: C3.2, J1.12, R20.2, U1.31 (NRST)
/MCU/OSC_IN: U1.29 (PH0), X4.3
/MCU/QSPI_BK1_CLK: U1.28 (PF10); also elsewhere on the board
/MCU/QSPI_BK1_IO0: U1.26 (PF8); also elsewhere on the board
/MCU/QSPI_BK1_IO1: U1.27 (PF9); also elsewhere on the board
/MCU/QSPI_BK1_IO2: U1.25 (PF7); also elsewhere on the board
/MCU/QSPI_BK1_IO3: U1.24 (PF6); also elsewhere on the board
/MCU/SPI2_MISO: U1.87 (PB14); also elsewhere on the board
/MCU/SPI2_MOSI: U1.88 (PB15); also elsewhere on the board
/MCU/SPI2_SCK: U1.133 (PI1); also elsewhere on the board
/MCU/UART_RX: J1.13, U1.125 (PA10)
/MCU/UART_TX: J1.14, U1.124 (PA9)
/MCU/USB_DN: U1.126 (PA11); also elsewhere on the board
/MCU/USB_DP: U1.127 (PA12); also elsewhere on the board
/MCU/VDDA: C23.1, C24.1, L1.2, R18.1, U1.39 (VDDA)
/MCU/~ETH_RESET: U1.67 (PG1); also elsewhere on the board
/MCU/~QSPI_BK1_NCS: U1.79 (PB10); also elsewhere on the board
/MCU/~SPI2_NSS: U1.132 (PI0); also elsewhere on the board
/RFID/IRQ: U1.18 (PF2); also elsewhere on the board
/RFID/PDOWN: U1.19 (PF3); also elsewhere on the board
/ZigBee/IRQ: U1.91 (PD10); also elsewhere on the board
/ZigBee/SLP_TR: U1.90 (PD9); also elsewhere on the board
/ZigBee/~RST: U1.89 (PD8); also elsewhere on the board
GND: C1.1, C2.1, C3.1, C4.1, C5.1, C6.1, C7.1, C8.1, C9.1, C10.1, C11.1, C12.1, C13.1, C14.1, C15.1, C16.1, C17.1, C18.2, C19.1, C20.1, C21.2, C22.2, C23.2, C24.2, C25.2, D2.1 (K), D3.1 (K), J1.5, J1.7, J1.11, R16.1, R17.1, U1.14 (VSS), U1.22 (VSS), U1.37 (VSSA), U1.61 (VSS), U1.71 (VSS), U1.95 (VSS), U1.103 (VSSDSI), U1.109 (VSSDSI), U1.117 (VSS), U1.130 (VSS), U1.135 (VSS), U1.148 (VSS), U1.158 (VSS), X4.2; also elsewhere on the board
unnamed: C1.2, U1.81 (VCAP1)
unnamed: C2.2, U1.129 (VCAP2)
unnamed: D2.2 (A), R50.1
unnamed: D3.2 (A), R51.1
unnamed: R16.2, U1.166 (BOOT0)
unnamed: R17.2, U1.48 (BYPASS_REG)
unnamed: R18.2, U1.38 (VREF+)
unnamed: R19.2, U1.171 (PDR_ON)
unnamed: R50.2, U1.112 (PG4)
unnamed: R51.2, U1.111 (PG3)

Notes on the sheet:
JTAG connector for STLink V3
STM32F469IIT Microcontroller
10 MHz Oscillator
I_max >= 350 mA

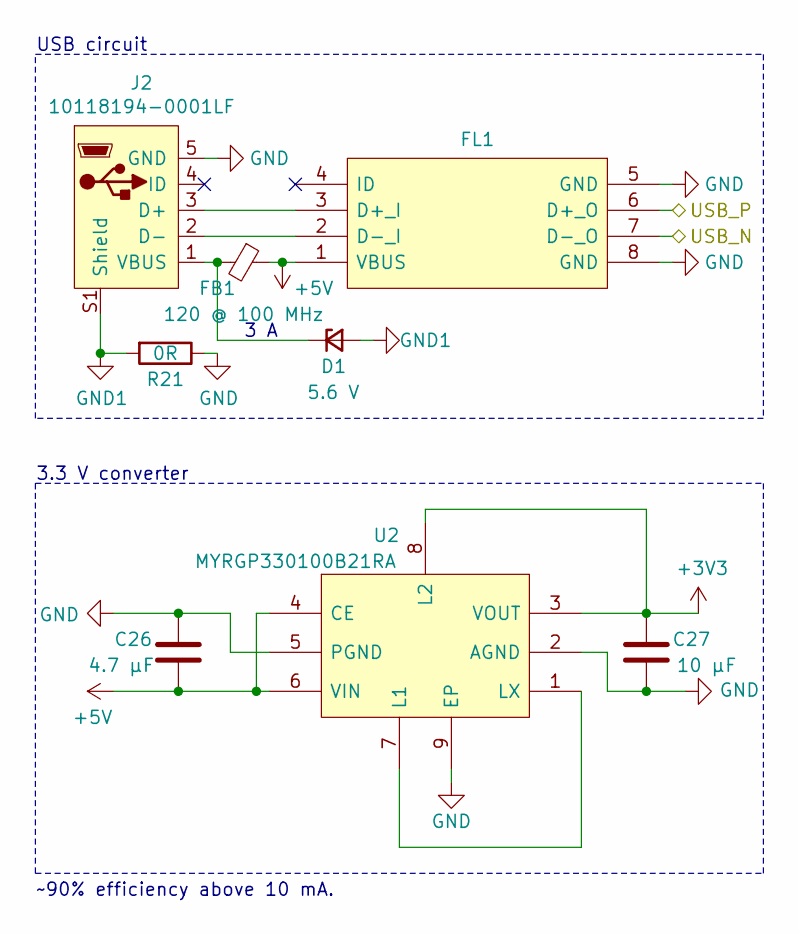
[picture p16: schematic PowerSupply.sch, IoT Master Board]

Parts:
C26: 4.7 µF; C_0805_2012Metric
C27: 10 µF; C_0805_2012Metric
D1: 5.6 V; D_MiniMELF
FB1: 120 @ 100 MHz; L_0603_1608Metric
FL1: ECMF02-4CMX8; ECMF024CMX8; Manufacturer_Part_Number ECMF02-4CMX8; Mouser Part Number 511-ECMF02-4CMX8
J2: 10118194-0001LF
R21: 0R; R_1206_3216Metric
U2: MYRGP330100B21RA; MYRGP180100B21RA

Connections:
+5V: C26.2, FB1.1, FL1.1 (VBUS), U2.4 (CE), U2.6 (VIN)
/MCU/USB_DN: FL1.7 (D-_O); also elsewhere on the board
/MCU/USB_DP: FL1.6 (D+_O); also elsewhere on the board
GND: C26.1, C27.1, FL1.5 (GND), FL1.8 (GND), J2.5 (GND), R21.1, U2.2 (AGND), U2.5 (PGND), U2.9 (EP); also elsewhere on the board
GND1: D1.2 (A), J2.S1 (Shield), R21.2
unnamed: D1.1 (K), FB1.2, J2.1 (VBUS)
unnamed: FL1.2 (D-_I), J2.2 (D-)
unnamed: FL1.3 (D+_I), J2.3 (D+)
unnamed: U2.1 (LX), U2.7 (L1)

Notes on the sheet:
3 A
USB circuit
3.3 V converter
~~90% efficiency above 10 mA.

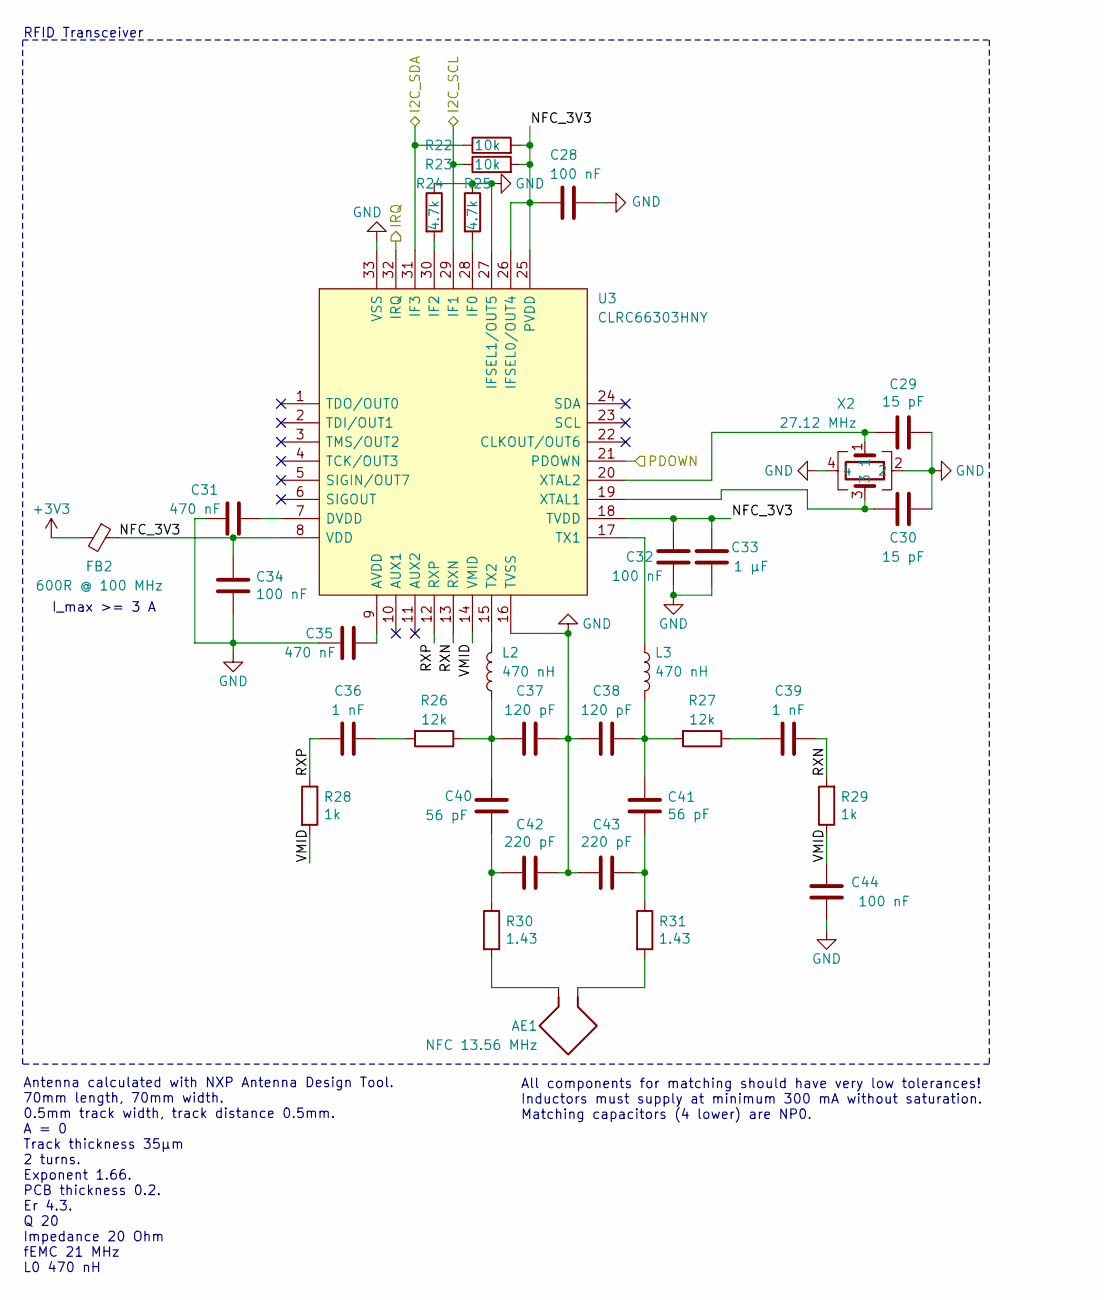
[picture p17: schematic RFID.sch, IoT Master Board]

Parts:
AE1: NFC 13.56 MHz; NXP_NFC_13.56MHz
C28, C32, C34, C44: 100 nF; C_0603_1608Metric
C29, C30: 15 pF; C_0603_1608Metric
C31, C35: 470 nF; C_0603_1608Metric
C33: 1 µF; C_0603_1608Metric
C36, C39: 1 nF; C_0603_1608Metric
C37, C38: 120 pF; C_0603_1608Metric
C40, C41: 56 pF; C_0603_1608Metric
C42, C43: 220 pF; C_0603_1608Metric
FB2: 600R @ 100 MHz; L_1210_3225Metric
L2, L3: 470 nH; SRN2512R47M
R22, R23: 10k; R_0603_1608Metric
R24, R25: 4.7k; R_0603_1608Metric
R26, R27: 12k; R_0603_1608Metric
R28, R29: 1k; R_0603_1608Metric
R30, R31: 1.43; R_0603_1608Metric
U3: CLRC66303HNY; Manufacturer_Part_Number CLRC66303HNY; Mouser Part Number 771-CLRC66303HNY
X2: 27.12 MHz; ECS27121037AGNTR

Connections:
/MCU/I2C2_SCL: R23.1, U3.29 (IF1); also elsewhere on the board
/MCU/I2C2_SDA: R22.1, U3.31 (IF3); also elsewhere on the board
/RFID/IRQ: U3.32 (IRQ); also elsewhere on the board
/RFID/NFC_3V3: C28.2, C32.2, C33.2, C34.1, FB2.1, R22.2, R23.2, U3.8 (VDD), U3.18 (TVDD), U3.25 (PVDD), U3.26 (IFSEL0/OUT4)
/RFID/PDOWN: U3.21 (PDOWN); also elsewhere on the board
/RFID/RXN: C39.1, R29.2, U3.13 (RXN)
/RFID/RXP: C36.1, R28.1, U3.12 (RXP)
/RFID/VMID: C44.1, R28.2, R29.1, U3.14 (VMID)
GND: C28.1, C29.1, C30.1, C31.2, C32.1, C33.1, C34.2, C35.1, C37.1, C38.2, C42.1, C43.2, C44.2, R24.1, R25.1, U3.16 (TVSS), U3.27 (IFSEL1/OUT5), U3.33 (VSS), X2.2, X2.4; also elsewhere on the board
unnamed: AE1.1, R31.2
unnamed: AE1.2, R30.2
unnamed: C29.2, U3.20 (XTAL2), X2.1
unnamed: C30.2, U3.19 (XTAL1), X2.3
unnamed: C31.1, U3.7 (DVDD)
unnamed: C35.2, U3.9 (AVDD)
unnamed: C36.2, R26.2
unnamed: C37.2, C40.2, L2.1, R26.1
unnamed: C38.1, C41.2, L3.2, R27.2
unnamed: C39.2, R27.1
unnamed: C40.1, C42.2, R30.1
unnamed: C41.1, C43.1, R31.1
unnamed: L2.2, U3.15 (TX2)
unnamed: L3.1, U3.17 (TX1)
unnamed: R24.2, U3.30 (IF2)
unnamed: R25.2, U3.28 (IF0)

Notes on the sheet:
All components for matching should have very low tolerances! Inductors must supply at minimum 300 mA without saturation. Matching capacitors (4 lower) are NP0.
I_max >= 3 A
Antenna calculated with NXP Antenna Design Tool. 70mm length, 70mm width. 0.5mm track width, track distance 0.5mm. A = 0 Track thickness 35µm 2 turns. Exponent 1.66. PCB thickness 0.2. Er 4.3. Q 20 Impedance 20 Ohm fEMC 21 MHz L0 470 nH
RFID Transceiver

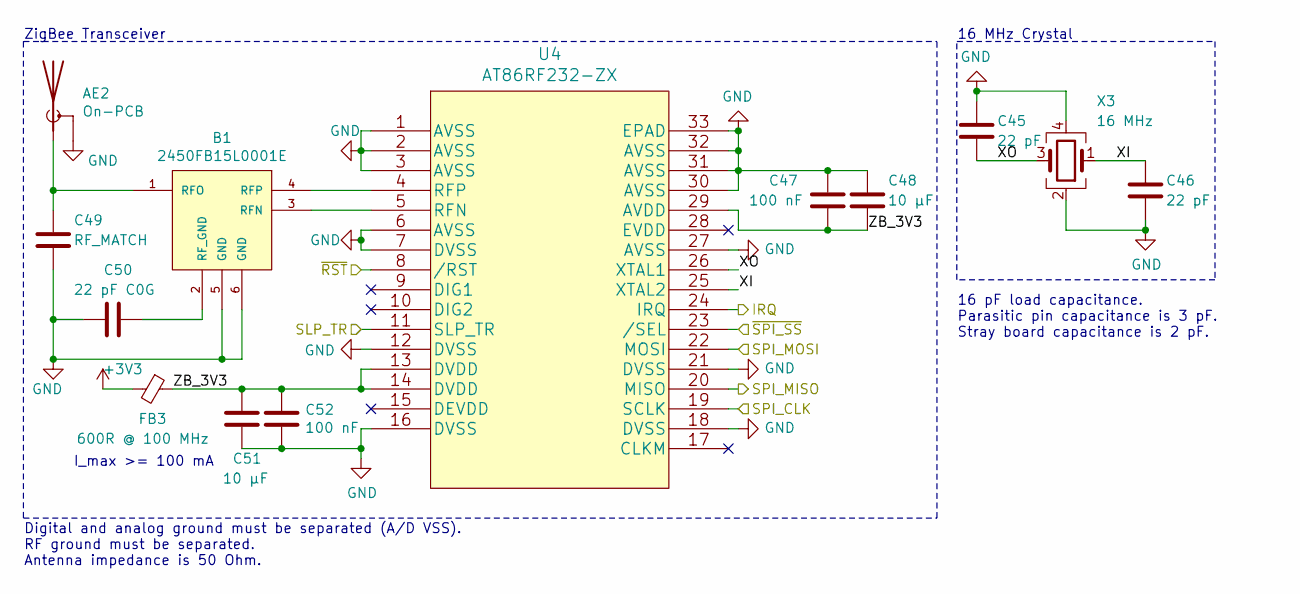
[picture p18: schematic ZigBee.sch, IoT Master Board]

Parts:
AE2: On-PCB; Texas_SWRA117D_2.4GHz_Left
B1: 2450FB15L0001E
C45, C46: 22 pF; C_0603_1608Metric
C47, C52: 100 nF; C_0603_1608Metric
C48, C51: 10 µF; C_0805_2012Metric
C49: RF_MATCH; C_0805_2012Metric
C50: 22 pF C0G; C_0402_1005Metric; Part 500R07S220JV4 recommended
FB3: 600R @ 100 MHz; L_0603_1608Metric
U4: AT86RF232-ZX
X3: 16 MHz; ECS1601633BCKMTR

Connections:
/MCU/SPI2_MISO: U4.20 (MISO); also elsewhere on the board
/MCU/SPI2_MOSI: U4.22 (MOSI); also elsewhere on the board
/MCU/SPI2_SCK: U4.19 (SCLK); also elsewhere on the board
/MCU/~SPI2_NSS: U4.23 (/SEL); also elsewhere on the board
/ZigBee/IRQ: U4.24 (IRQ); also elsewhere on the board
/ZigBee/SLP_TR: U4.11 (SLP_TR); also elsewhere on the board
/ZigBee/XI: C46.1, U4.25 (XTAL2), X3.1
/ZigBee/XO: C45.2, U4.26 (XTAL1), X3.3
/ZigBee/ZB_3V3: C47.2, C48.2, C51.1, C52.1, FB3.1, U4.13 (DVDD), U4.14 (DVDD), U4.29 (AVDD)
/ZigBee/~RST: U4.8 (/RST); also elsewhere on the board
GND: AE2.2 (Shield), B1.5 (GND), B1.6 (GND), C45.1, C46.2, C47.1, C48.1, C49.2, C50.2, C51.2, C52.2, U4.1 (AVSS), U4.2 (AVSS), U4.3 (AVSS), U4.6 (AVSS), U4.7 (DVSS), U4.12 (DVSS), U4.16 (DVSS), U4.18 (DVSS), U4.21 (DVSS), U4.27 (AVSS), U4.30 (AVSS), U4.31 (AVSS), U4.32 (AVSS), U4.33 (EPAD), X3.2, X3.4; also elsewhere on the board
unnamed: AE2.1 (A), B1.1 (RFO), C49.1
unnamed: B1.2 (RF_GND), C50.1
unnamed: B1.3 (RFN), U4.5 (RFN)
unnamed: B1.4 (RFP), U4.4 (RFP)

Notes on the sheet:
16 pF load capacitance. Parasitic pin capacitance is 3 pF. Stray board capacitance is 2 pF.
16 MHz Crystal
Digital and analog ground must be separated (A/D VSS). RF ground must be separated. Antenna impedance is 50 Ohm.
ZigBee Transceiver
I_max >= 100 mA

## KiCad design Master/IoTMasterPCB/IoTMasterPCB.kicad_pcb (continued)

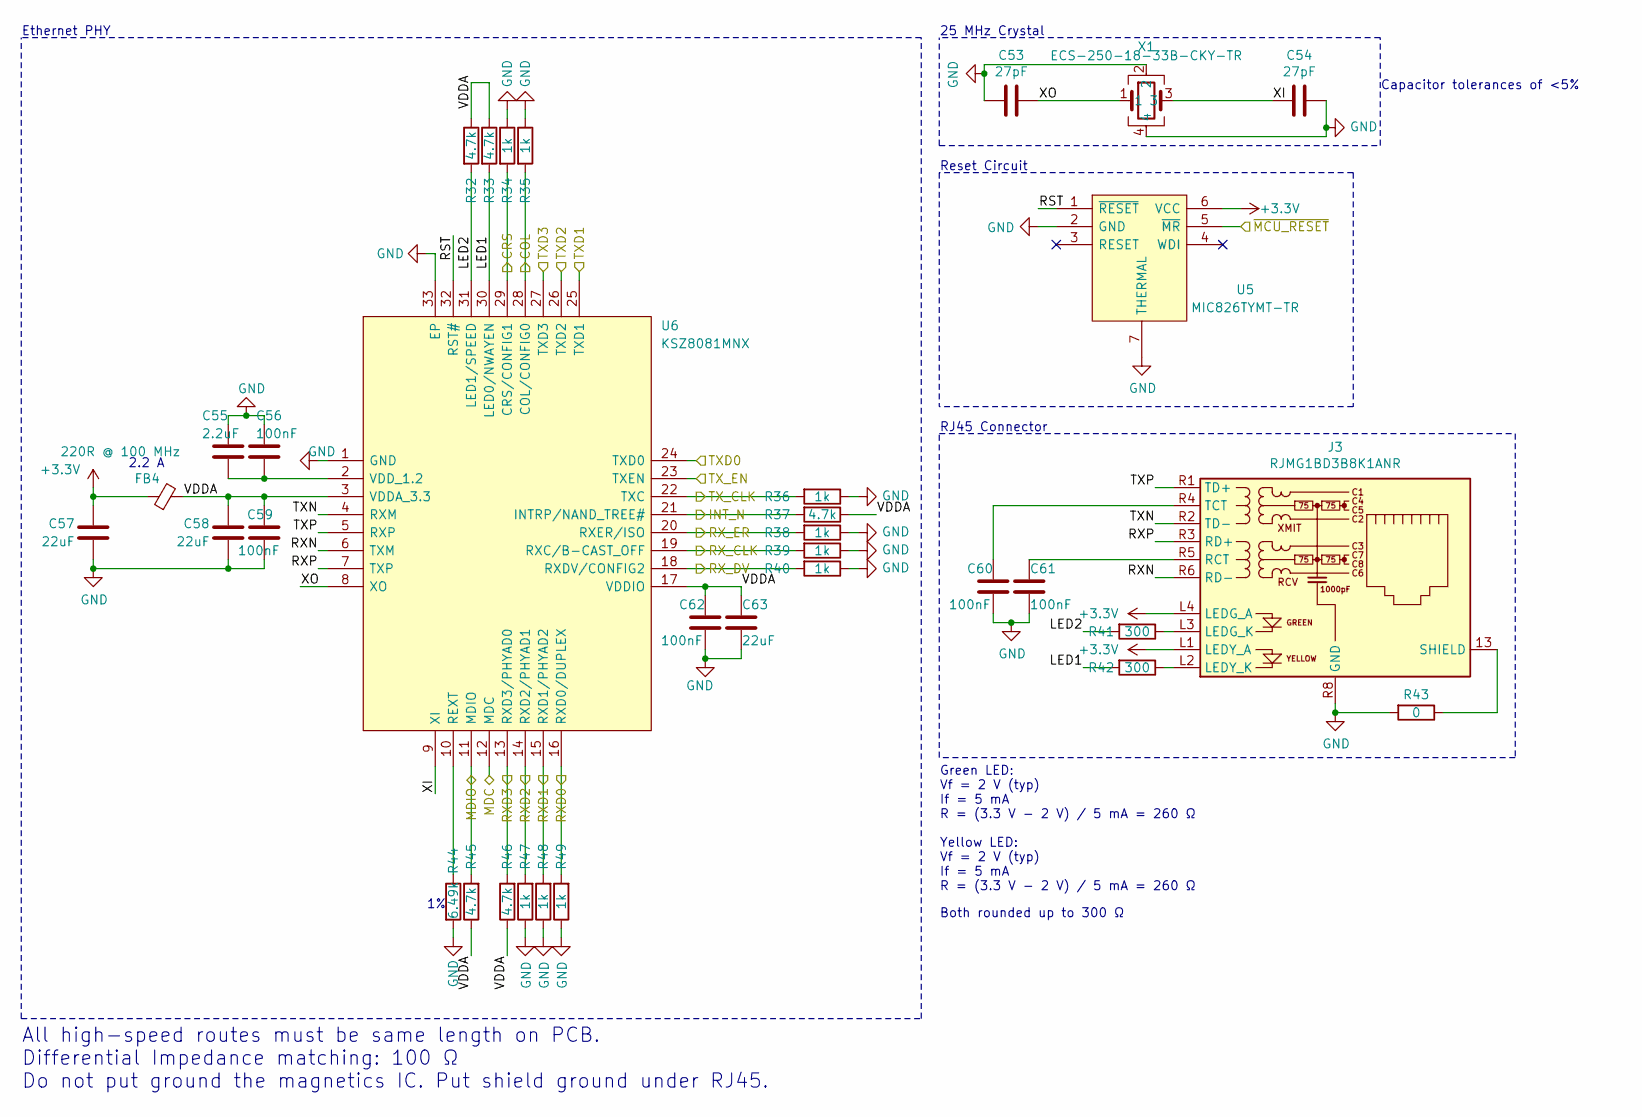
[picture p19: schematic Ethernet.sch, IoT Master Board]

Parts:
C53, C54: 27pF; C_0603_1608Metric
C55: 2.2uF; C_0603_1608Metric
C56, C59, C60, C61, C62: 100nF; C_0603_1608Metric
C57, C58: 22uF; C_1206_3216Metric
C63: 22uF; C_0603_1608Metric
FB4: 220R @ 100 MHz; L_0603_1608Metric
J3: RJMG1BD3B8K1ANR
R32, R33, R37, R45, R46: 4.7k; R_0603_1608Metric
R34, R35, R36, R38, R39, R40, R47, R48, R49: 1k; R_0603_1608Metric
R41, R42: 300; R_0603_1608Metric
R43: 0; R_1206_3216Metric
R44: 6.49k; R_0603_1608Metric
U5: MIC826TYMT-TR; Manufacturer_Part_Number MIC826TYMT-TR; Mouser Part Number 998-MIC826TYMTTR
U6: KSZ8081MNX
X1: ECS-250-18-33B-CKY-TR; ECS-250-18-33B-CKY; Manufacturer_Part_Number ECS-250-20-33-TR; Mouser Part Number 520-ECS-250-20-33

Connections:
/Ethernet/COL: R35.2, U6.28 (COL/CONFIG0); also elsewhere on the board
/Ethernet/CRS: R34.2, U6.29 (CRS/CONFIG1); also elsewhere on the board
/Ethernet/LED1: R33.2, R42.2, U6.30 (LED0/NWAYEN)
/Ethernet/LED2: R32.2, R41.2, U6.31 (LED1/SPEED)
/Ethernet/RST: U5.1 (~RESET), U6.32 (RST#)
/Ethernet/RXD0: R49.2, U6.16 (RXD0/DUPLEX); also elsewhere on the board
/Ethernet/RXD1: R48.2, U6.15 (RXD1/PHYAD2); also elsewhere on the board
/Ethernet/RXD2: R47.2, U6.14 (RXD2/PHYAD1); also elsewhere on the board
/Ethernet/RXD3: R46.2, U6.13 (RXD3/PHYAD0); also elsewhere on the board
/Ethernet/RXN: J3.R6 (RD-), U6.6 (TXM)
/Ethernet/RXP: J3.R3 (RD+), U6.7 (TXP)
/Ethernet/RX_CLK: R39.2, U6.19 (RXC/B-CAST_OFF); also elsewhere on the board
/Ethernet/RX_DV: R40.2, U6.18 (RXDV/CONFIG2); also elsewhere on the board
/Ethernet/RX_ER: R38.2, U6.20 (RXER/ISO); also elsewhere on the board
/Ethernet/TXD0: U6.24 (TXD0); also elsewhere on the board
/Ethernet/TXD1: U6.25 (TXD1); also elsewhere on the board
/Ethernet/TXD2: U6.26 (TXD2); also elsewhere on the board
/Ethernet/TXD3: U6.27 (TXD3); also elsewhere on the board
/Ethernet/TXN: J3.R2 (TD-), U6.4 (RXM)
/Ethernet/TXP: J3.R1 (TD+), U6.5 (RXP)
/Ethernet/TX_CLK: R36.2, U6.22 (TXC); also elsewhere on the board
/Ethernet/TX_EN: U6.23 (TXEN); also elsewhere on the board
/Ethernet/VDDA: C58.2, C59.1, C62.1, C63.1, FB4.2, R32.1, R33.1, R37.1, R45.1, R46.1, U6.3 (VDDA_3.3), U6.17 (VDDIO)
/Ethernet/XI: C54.1, U6.9 (XI), X1.3
/Ethernet/XO: C53.1, U6.8 (XO), X1.1
/MCU/ETH_INT: R37.2, U6.21 (INTRP/NAND_TREE#); also elsewhere on the board
/MCU/ETH_MDC: U6.12 (MDC); also elsewhere on the board
/MCU/ETH_MDIO: R45.2, U6.11 (MDIO); also elsewhere on the board
/MCU/~ETH_RESET: U5.5 (~MR); also elsewhere on the board
GND: C53.2, C54.2, C55.1, C56.1, C57.1, C58.1, C59.2, C60.2, C61.2, C62.2, C63.2, J3.R8 (GND), R34.1, R35.1, R36.1, R38.1, R39.1, R40.1, R43.2, R44.2, R47.1, R48.1, R49.1, U5.2 (GND), U5.7 (THERMAL), U6.1 (GND), U6.33 (EP), X1.2, X1.4; also elsewhere on the board
unnamed: C55.2, C56.2, U6.2 (VDD_1.2)
unnamed: C60.1, J3.R4 (TCT)
unnamed: C61.1, J3.R5 (RCT)
unnamed: J3.13 (SHIELD), R43.1
unnamed: J3.L2 (LEDY_K), R42.1
unnamed: J3.L3 (LEDG_K), R41.1
unnamed: R44.1, U6.10 (REXT)

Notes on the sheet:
Ethernet PHY
2.2 A
Yellow LED: Vf = 2 V (typ) If = 5 mA R = (3.3 V - 2 V) / 5 mA = 260 Ω
Both rounded up to 300 Ω
25 MHz Crystal
Reset Circuit
Green LED: Vf = 2 V (typ) If = 5 mA R = (3.3 V - 2 V) / 5 mA = 260 Ω
Capacitor tolerances of <5%
RJ45 Connector
All high-speed routes must be same length on PCB. Differential Impedance matching: 100 Ω Do not put ground the magnetics IC. Put shield ground under RJ45.


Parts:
C64: 100 nF; C_0603_1608Metric
U7: W25Q32JVSS; SOIC-8_5.23x5.23mm_P1.27mm

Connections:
/MCU/QSPI_BK1_CLK: U7.6 (CLK); also elsewhere on the board
/MCU/QSPI_BK1_IO0: U7.5 (DI(IO0)); also elsewhere on the board
/MCU/QSPI_BK1_IO1: U7.2 (DO(IO1)); also elsewhere on the board
/MCU/QSPI_BK1_IO2: U7.3 (IO2); also elsewhere on the board
/MCU/QSPI_BK1_IO3: U7.7 (IO3); also elsewhere on the board
/MCU/~QSPI_BK1_NCS: U7.1 (~CS); also elsewhere on the board
GND: C64.1, U7.4 (GND); also elsewhere on the board

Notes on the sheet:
32 Mbit NOR Flash

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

Board: 4 copper layers, 139.5 x 81.2 mm, 143 parts (0 on the bottom side), 125 nets.

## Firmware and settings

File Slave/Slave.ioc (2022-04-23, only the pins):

Mcu.UserName=STM32L412RBTxP
PA10.Signal=I2C1_SDA
PA2.Signal=QUADSPI_BK1_NCS
PA3.Signal=QUADSPI_CLK
PA6.Signal=QUADSPI_BK1_IO3
PA7.Signal=QUADSPI_BK1_IO2
PA9.Signal=I2C1_SCL
PB0.Signal=QUADSPI_BK1_IO1
PB1.Signal=QUADSPI_BK1_IO0
PB10.Signal=SPI2_SCK
PB12.Signal=SPI2_NSS
PB6.Signal=USART1_TX
PB7.Signal=USART1_RX
PC0.Signal=ADCx_IN1
PC2.Signal=SPI2_MISO
PC3.Signal=SPI2_MOSI
PC6.GPIO_Label=RF_RST
PC6.Signal=GPIO_Output
PC7.GPIO_Label=RF_SLP_TR
PC7.Signal=GPIO_Output
PC8.GPIO_Label=RF_IRQ
PC8.Signal=GPIO_Input

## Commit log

2020-10-31 STM32CubeMX files added for both master and slave.
2020-11-01 Added block diagrams for both boards, modifications to CubeMX file.
    [IoTMasterPCB.kicad_pcb, IoTMasterPCB.sch, IoTSlavePCB.kicad_pcb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]
2020-11-01 Setup schematics for both master and slave. Minor changes to MX configurations. Started design of slaves.
    [Ethernet.sch, JTAG.sch, MCU.sch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]
2020-11-06 Continued work on slaves. Added sensor and begun work on ZigBee transceiver.
    [IoTSlavePCB.sch, MCU.sch, PowerSupply.sch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]
2020-11-23 Finished slave schematics, including memory and Zigbee Transceiver. Further work on PCB, well underway.
    [IoTSlavePCB.sch, MCU.sch, Memory.sch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]
2020-11-24 Made more connections on PCB, some optimizations. Added silk screen text.
    [IoTSlavePCB.kicad_pcb, IoTSlavePCB.sch, MCU.sch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]
2020-11-24 Everything placed. Only needs final routes and optimization.
    [IoTSlavePCB.kicad_pcb, ZigBee.sch]
2020-11-26 Further PCB work.
    [IoTSlavePCB.kicad_pcb]
2020-11-27 Prettified PCB, some changes to routes and planes for performance.
    [IoTSlavePCB.kicad_pcb]
2020-11-28 Change for clarity.
    [IoTSlavePCB.kicad_pcb, PowerSupply.sch]
2020-11-28 Added battery voltage measurement circuit. Optimizations to antenna and general component placement.
    [IoTSlavePCB.kicad_pcb, IoTSlavePCB.sch, MCU.sch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]
2020-11-28 Updated Master Board schematics. Added JTAG connector.
    [Ethernet.sch, IoTMasterPCB.sch, MCU.sch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]
2020-12-05 Added some components for Master Board schematic.
    [Ethernet.sch, JTAG.sch, PowerSupply.sch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]
2020-12-05 Work on Master Board schematics; added full Zigbee. Added RFID module. Added USB/power supply, as well as MCU decoupling.
    [IoTMasterPCB.sch, MCU.sch, PowerSupply.sch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]
2020-12-07 Added flash storage, work on RFID front-end.
    [Ethernet.sch, Flash.sch, IoTMasterPCB.sch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]
2020-12-10 Finished RFID module sans antenna footprint. Added KSZ8081MNX and hierarchial connections.
    [Ethernet.sch, Flash.sch, IoTMasterPCB.sch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]
2020-12-11 Finished RFID and Ethernet circuits.
    [Ethernet.sch, Flash.sch, IoTMasterPCB.sch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]
2020-12-18 Minor changes to schematics, started work on PCB layout.
    [Flash.sch, PowerSupply.sch, RFID.sch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]
2020-12-23 Placed STM32 on Master PCB. Corrected I2C naming.
    [IoTMasterPCB.kicad_pcb, IoTMasterPCB.sch, PowerSupply.sch]
2021-01-21 More work on PCB layout, as wel as generation of LWIP (Ethernet) demo program for Master.
    [IoTMasterPCB.kicad_pcb]
2021-01-28 Minor changes to schematic, finished placing all components, only minor fixes needed to PCB now.
    [Ethernet.sch, IoTMasterPCB.kicad_pcb, MCU.sch]
2021-02-08 Finished Master PCB layout. Added revised LWIP Master Demo for STM32F769 discovery board, which has been confirmed to work by setting up at web page.
    [IoTMasterPCB.kicad_pcb, IoTSlavePCB.kicad_pcb]
2021-02-13 Added further documentation in ReadMe. Added status LEDs to Master.
    [IoTMasterPCB.kicad_pcb, MCU.sch, PowerSupply.sch]
2021-02-14 Added Slave demo program for use with STM32L412RB Nucleo board.
2022-04-23 Merge of recent changes to default master (#1)
    * Made changes to folder structure, added documentation.
    * Minor changes to PCBs, created demo for wireless communication.
    [IoTMasterPCB.kicad_pcb, IoTSlavePCB.kicad_pcb]

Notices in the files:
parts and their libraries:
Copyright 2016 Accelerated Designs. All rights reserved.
